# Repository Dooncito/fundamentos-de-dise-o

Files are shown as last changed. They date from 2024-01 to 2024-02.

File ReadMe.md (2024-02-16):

# <p align="center"> Análisis sobre la contaminación atmósfera por las causas de combustibles contaminantes📊 </p>

Proyecto de monitoreo del CO,CO2 y particulas PM2.5 emitidas por el uso de comsbustibles fósiles. 
Datos de experimentales:

- Co (monoxido de carbono):
- CO2 (dioxido de carbono):

- Pm2.5 (materia particulado 2.5):

Plataforma para ver los datos:
https://stem.ubidots.com/app/dashboards/

usuario: doncito;
contraseña: Rodigro17daniel

Si desea conoce más de nosotros [dale click AQUI.](https://github.com/Dooncito/fundamentos-de-dise-o/blob/main/FdD/Entregables/Sobre_nosotros.md)

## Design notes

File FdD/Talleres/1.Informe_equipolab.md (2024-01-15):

## INTRODUCCIÓN A LOS EQUIPOS E INSTRUMENTOS DEL LABORATORIO 
Se muestra lo desarrollado en el laboratorio para conocer y manipular los equipos e instrumentos electrónicos básicos, además reconoce y verifica las características de medición eléctrica con el multímetro.

### Indice:

* [Materiales](#materiales)
* [Uso del multímetro y Fuente de alimentación](#uso-del-multímetro-y-fuente-de-alimentación)
   * [Promedio de errores absoluto y relativo](#promedio-de-errores-absoluto-y-relativo)
   * [Fotos de los Datos](#fotos-de-todos-los-datos)
* [Uso del Generador de Señales y Osciloscopio](#uso-del-generador-de-señales-y-osciloscopio) 
  * [Valores ajustados de la grafica](#valores-ajustados-de-la-grafica) 
  * [Valores medidos de la señal de entrada en un periodo](#valores-medidos-de-la-señal-de-entrada-en-un-periodo)

Documento: https://docs.google.com/document/d/15lO--RKTINXHAl-uv1xj17NnePU8hNBNqTpfqMAFmqM/edit?usp=sharing

## Materiales
   * Fuente de alimentación regulable (HY3005BC )
   * Multímetro Digital (UT139C)
   * Generador de Señales (AFG1022)
   * Osciloscopio Digital (TBS 1000C Series)
   * Cable BNC Male-Male 
   * Par de cables cocodrilos
   * Punta de osciloscopio con conector BNC (Male)

## Uso del multímetro y Fuente de alimentación

### Promedio de errores absoluto y relativo:
<div style="text-align:center;">
	<table border="1" style="margin: 0 auto;">
		<tr>
            <td>N°</td>
			<td>Valor Real</td>
			<td>Valor medio</td>
            <td>Error Absoluto</td>
            <td>Error relativo</td>
		</tr>
		<tr>
			<td>1</td>
			<td>5.00 V</td>
            <td>5.00 V</td>
            <td>0.00 V</td>
            <td>0%</td>
		</tr>
		<tr>
			<td>2</td>
			<td>6.00 V</td>
            <td>5.99 V</td>
            <td>0.01 V</td>
            <td>0.16% - 0.0016</td>
		</tr>
		<tr>
			<td>3</td>
			<td>7.00 V</td>
            <td>6.98 V<d>
            <td>0.02 V</td>
            <td>0.286% - 0.00286</td>
		</tr>
        <tr>
			<td>4</td>
			<td>8.00 V</td>
            <td>7.98 V</td>
            <td>0.01 V</td>
            <td>0.125% - 0.00125</td>
		</tr>
        <tr>
			<td>5</td>
			<td>9.00 V</td>
            <td>8.98 V</td>
            <td>0.02 V</td>
            <td>0.2% - 0.002</td>
		</tr>
        <tr>
			<td>6</td>
			<td>10.00 V</td>
            <td>9.98 V</td>
            <td>0.02 V</td>
            <td>0.2% - 0.002</td>
		</tr>
        <tr>
			<td>7</td>
			<td>11.00 V</td>
            <td>10.98 V</td>
            <td>0.02 V</td>
            <td>0.18% - 0.0018</td>
		</tr>
        <tr>
			<td>8</td>
			<td>12.00 V</td>
            <td>11.98 V</td>
            <td>0.02 V</td>
            <td>0.16% - 0.0016 </td>
		</tr>
        <tr>
			<td>9</td>
			<td>13.00 V</td>
            <td>12.98 V</td>
            <td>0.02 V</td>
            <td>0.154% - 0.00154</td>
		</tr>
        <tr>
			<td>10</td>
			<td>14.00 V</td>
            <td>13.97 V</td>
            <td>0.03 V</td>
            <td>0.214% - 0.002143</td>
		</tr>
        <tr>
			<td colspan="3">Promedio</td>
			<td> 0.017 V</td>
            <td>0.1679% </td>
		</tr>      
	</table>
    </div>
		    
### Fotos de todos los datos

| <!-- --> | <!-- --> | 
|:---:|:---:|
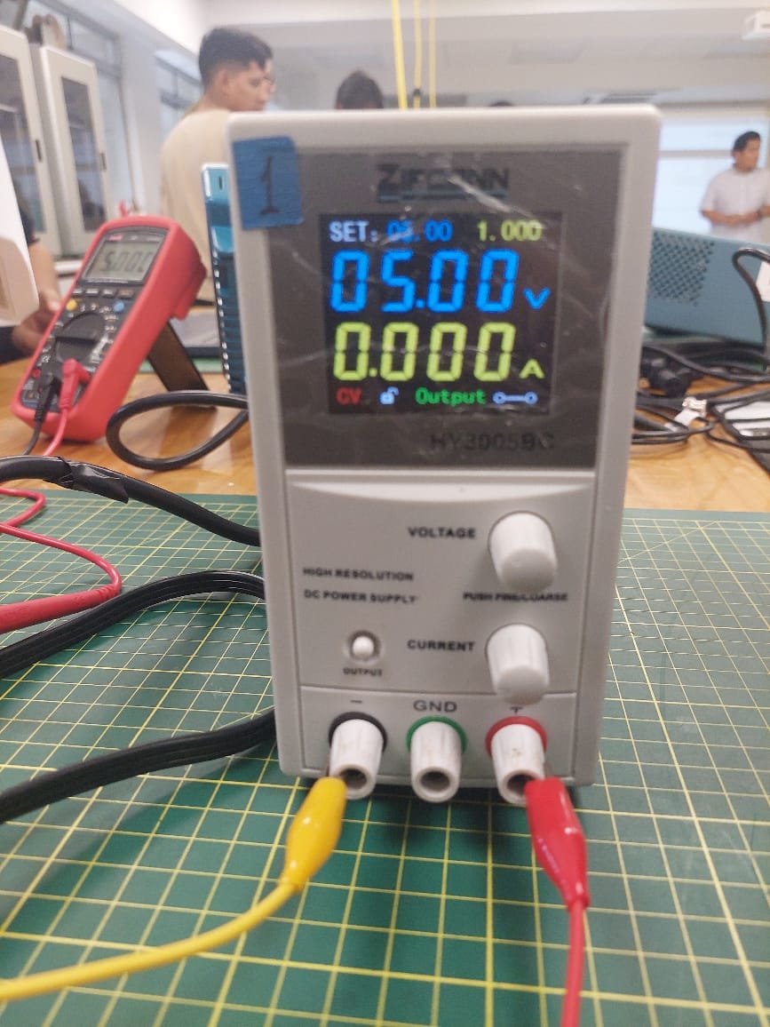
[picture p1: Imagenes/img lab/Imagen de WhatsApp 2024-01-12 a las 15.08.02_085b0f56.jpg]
Dato1
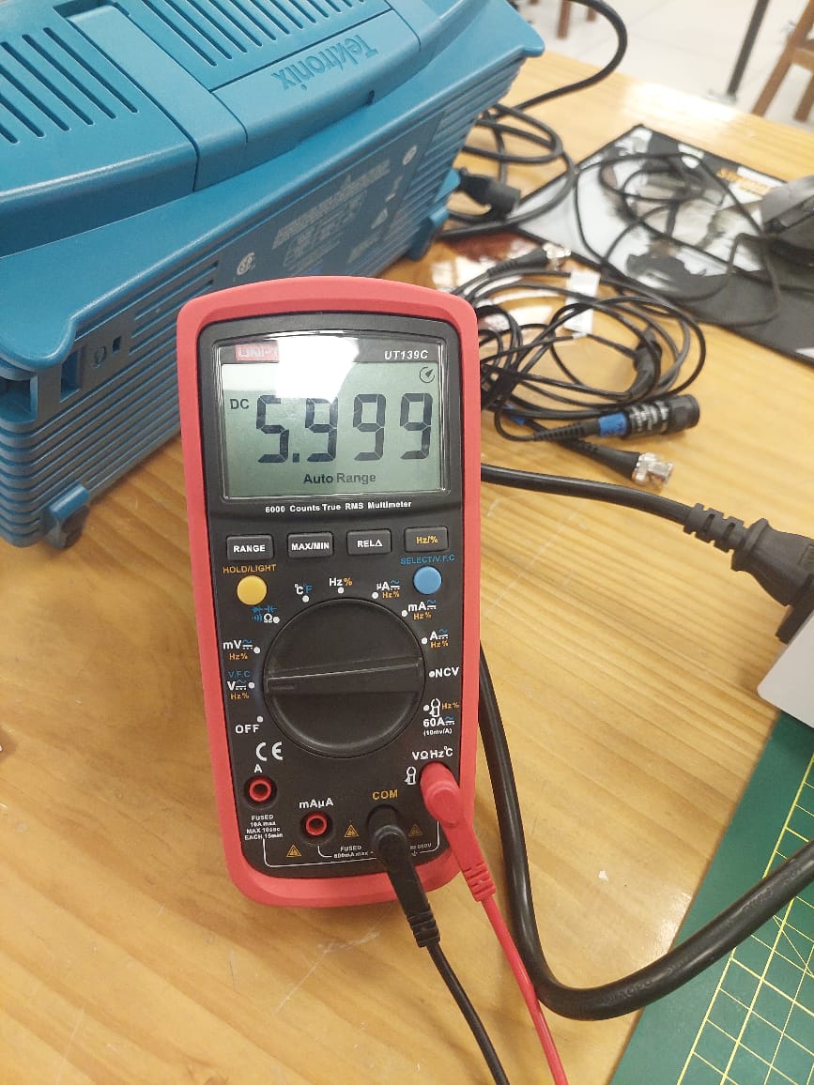
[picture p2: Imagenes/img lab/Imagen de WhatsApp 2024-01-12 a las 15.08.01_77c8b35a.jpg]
dato2
| |   |
| Dato#1 5V | Dato#2 6V | 
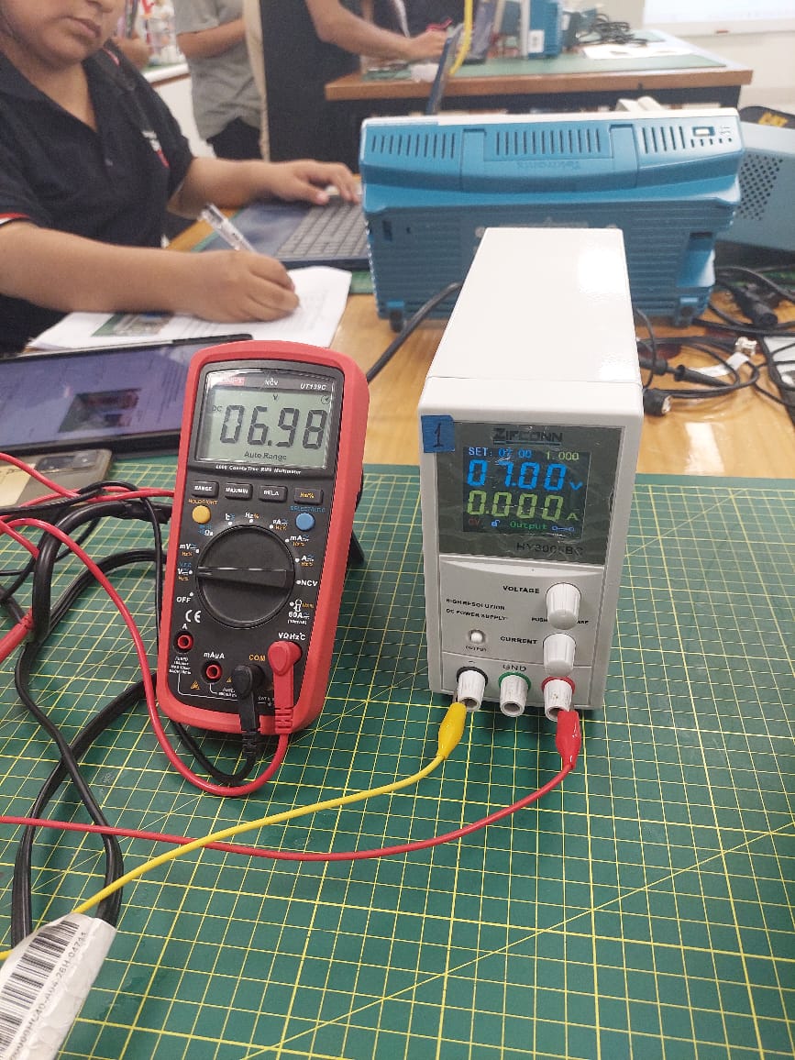
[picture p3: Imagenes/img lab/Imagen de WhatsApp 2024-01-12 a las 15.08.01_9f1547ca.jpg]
Dato3
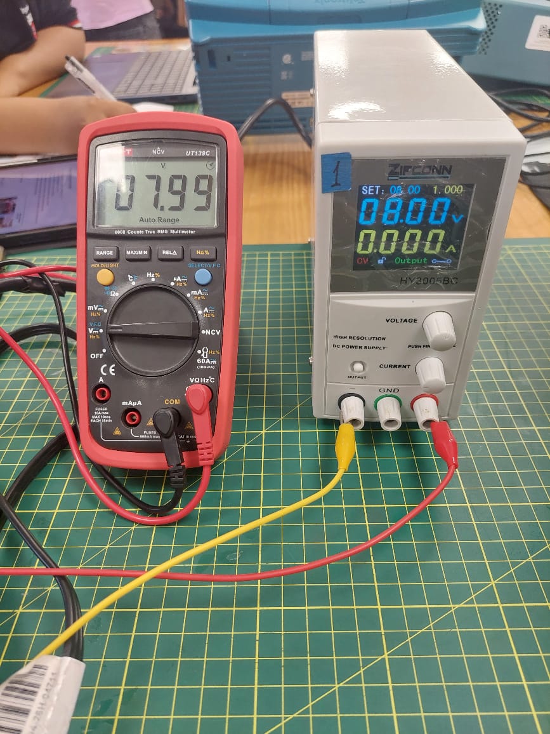
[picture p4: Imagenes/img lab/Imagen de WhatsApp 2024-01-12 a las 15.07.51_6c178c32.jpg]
dato4
| |   |
| Dato#3 7V | Dato#4 8V | 
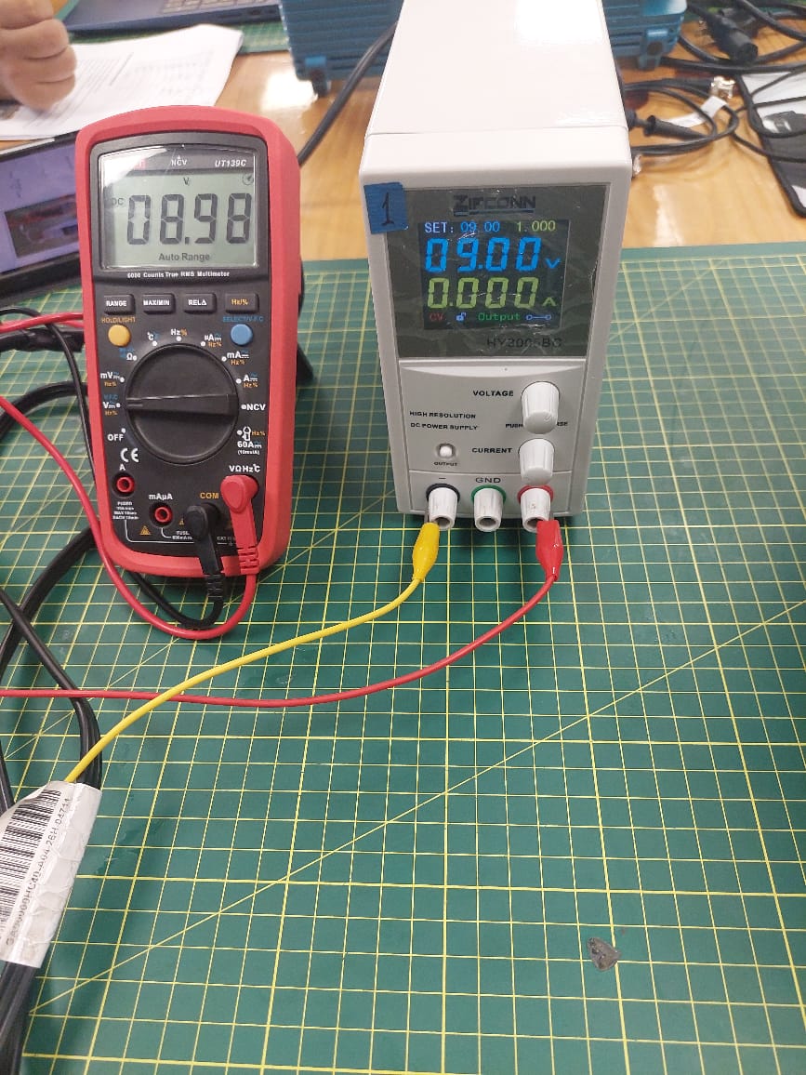
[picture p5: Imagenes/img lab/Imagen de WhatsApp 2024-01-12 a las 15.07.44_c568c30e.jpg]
Dato5
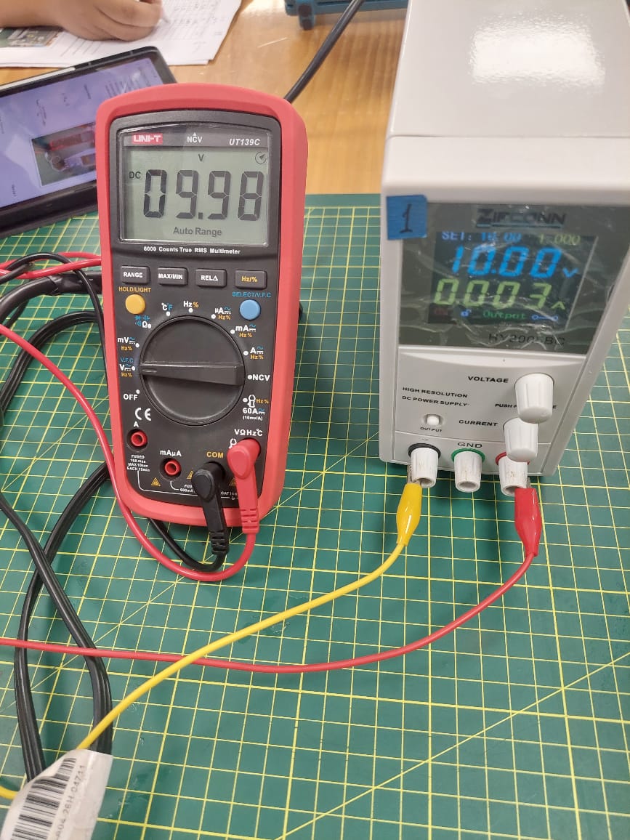
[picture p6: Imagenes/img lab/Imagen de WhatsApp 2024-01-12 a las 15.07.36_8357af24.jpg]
dato6
| |   |
| Dato#5 9V | Dato#6 10V | 
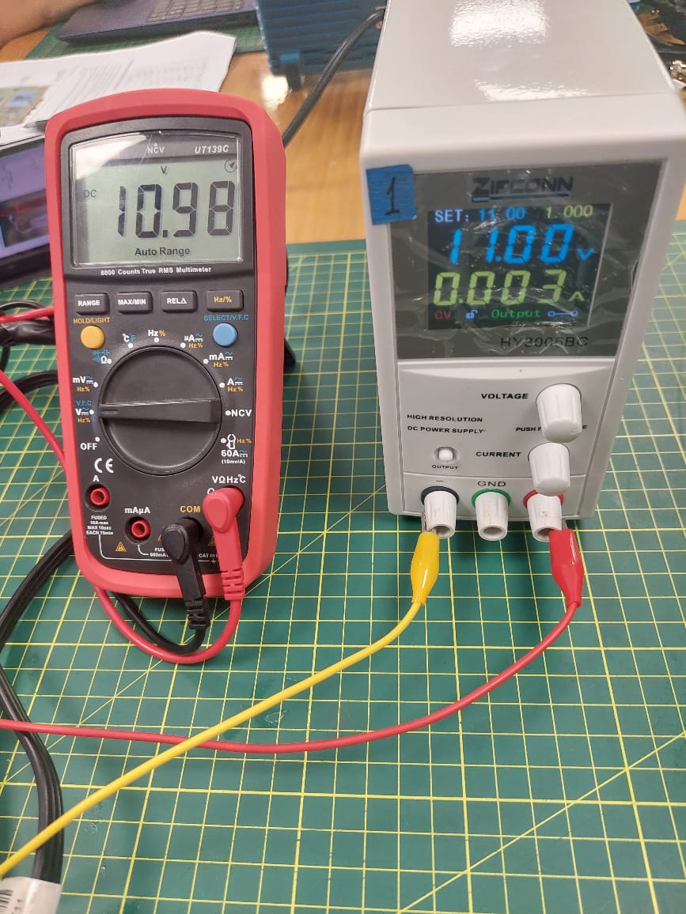
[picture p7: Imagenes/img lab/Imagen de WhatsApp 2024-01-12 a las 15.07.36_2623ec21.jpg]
Dato7
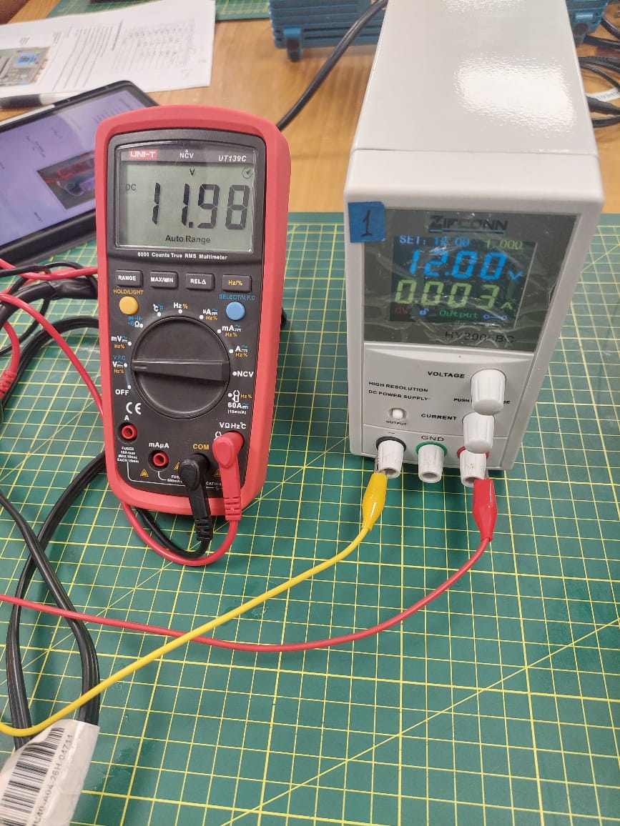
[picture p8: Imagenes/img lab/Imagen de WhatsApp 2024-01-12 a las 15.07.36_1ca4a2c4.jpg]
dato8
| |   |
| Dato#7 11V | Dato#8 12V | 
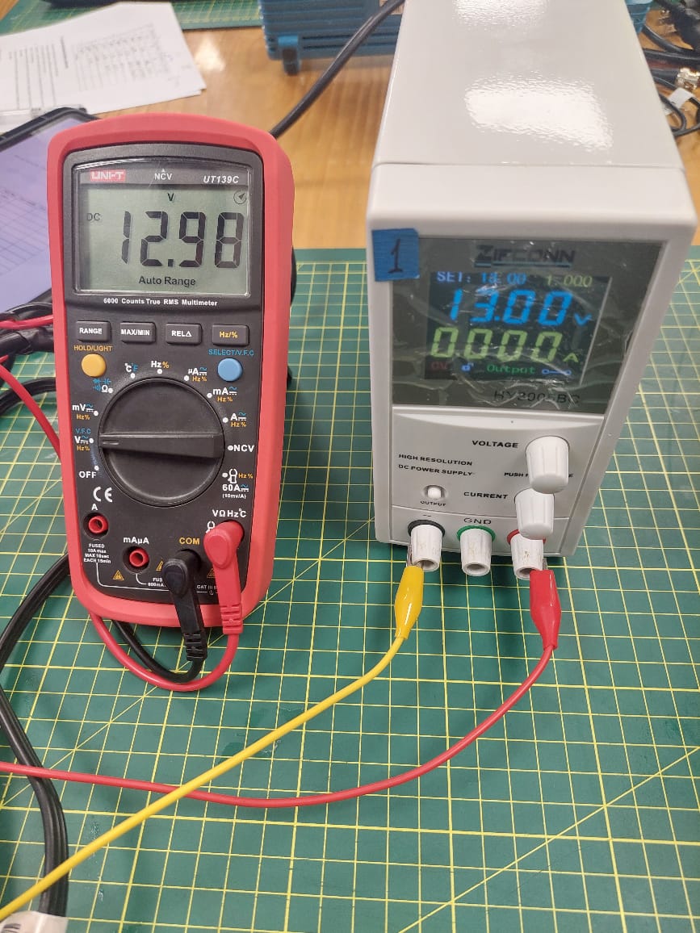
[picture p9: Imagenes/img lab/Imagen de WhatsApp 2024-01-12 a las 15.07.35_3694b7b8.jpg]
Dato9
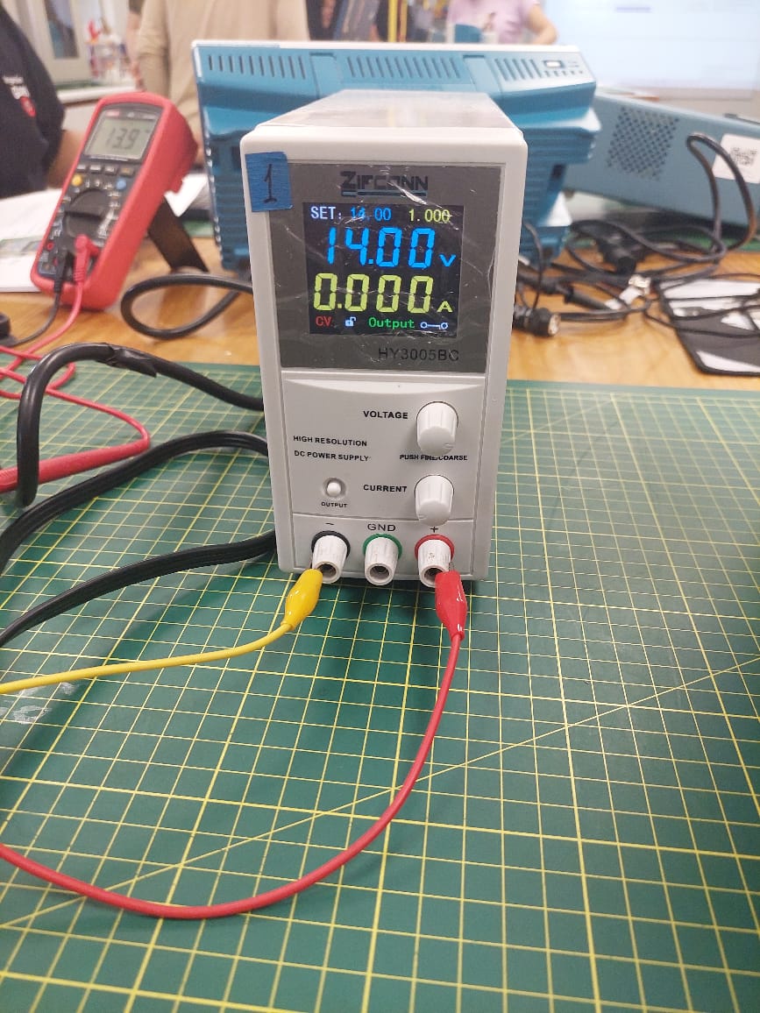
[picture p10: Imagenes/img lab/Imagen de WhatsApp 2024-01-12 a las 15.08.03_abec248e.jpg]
dato10
| |   |
| Dato#9 13V | Dato#10 14V | 

## Uso del Generador de Señales y Osciloscopio

En este experimento la consigna era modificar los parámetros de posición horizontal, vertical y disparo para ajustar la visualización de la señal sinusoidal en el osciloscopio, la cual es obtenida mediante el generador de señales.

Función de los instrumentos usados en esta sesión:

- Generador de señales: Emite señales eléctricas de frecuencias y amplitudes específicas, esencial para probar, calibrar y experimentar con dispositivos electrónicos.

- Osciloscopio digital: Muestra visualmente la forma de onda de señales, permitiendo a los técnicos analizar la amplitud, frecuencia y otros parámetros, con capacidades avanzadas de procesamiento y almacenamiento de datos

Primero conectamos mediante un cable BNC a ambos dispositivos en el canal 1, posteriormente ajustamos el generador de señales en los siguientes parámetros:

 - Frecuencia: 10khz
 - Amplitud: 2,5V
 - Offset: 0V

Descripción de la imagen

### Valores ajustados de la grafica

Se ajustaron los siguientes valores para sincronizar el voltaje en el osciloscopio:
- Escala de división vertical: 665V
- Amplitud máxima: 2.5kV
- Amplitud mínima: 0V
- Tiempo: 20μs
- Tasa de muestreo: 62,5MS/s
- Tiempo de registro: 20k ptos

Valores encontrados post-ajustes:
- Frecuencia: 10kHZ
- Voltaje pico: 1,01kV
- Variación de amplitud: 2,5kV

Al final nó se lograron obtener los valores solicitados, debido a que el valor de la escala de división vertical fue ajustado erroneamente en 665V.

### Valores medidos de la señal de entrada en un periodo 
Valores:
Amplitud: 2.50kV , Periodo: 100 ,Frecuencia : 1/ 100 = 0.01

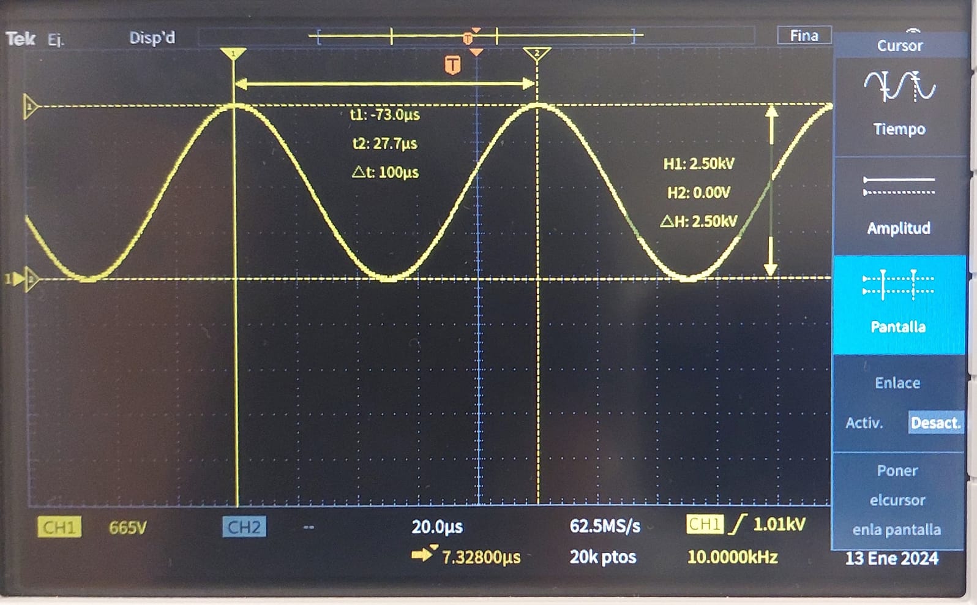
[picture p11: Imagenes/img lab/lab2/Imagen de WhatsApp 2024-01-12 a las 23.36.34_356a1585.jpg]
Descripción de la imagen


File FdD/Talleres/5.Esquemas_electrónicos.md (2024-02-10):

# <h1 align= "center"> **Esquemático del circuito electrónico**</h1>

### Integrantes:
* Said Andre Quispe Diaz
* Hermoza Quispe, Daniel Rodrigo
* Acevedo Valer, Milagros Soledad
* Jander Huamani Salazar
### Lista de contenido:
* [Introducción](#introducción) 
* [Objetivo](#objetivo)
* [Plataforma](#¿cuáles-son-las-ventajas-de-utilizar-la-plataforma-fluxia)
* [Componentes](#componentes-a-utilizar)
* [Desarrollo](#explicación-del-esquema)
* [Esquema](#esquema-del-ejercicio)

### Introducción: 
  El esquemático del circuito electrónico es esencial en todas las etapas del ciclo de vida de un proyecto electrónico, desde el diseño inicial hasta la implementación y el mantenimiento. Proporciona una representación visual clara y concisa que facilita el diseño, análisis, documentación y comunicación de los circuitos electrónicos.
### Objetivo: 
En el presente taller se utilizará la IA Flux como plataforma para la creación del esquemático de circuito eléctrico, en la cual usaremos como mínimo 6 componentes para dicha creación, mencionando el uso que tendrá cada componentes dentro del esquema de circuito eléctrico .
### ¿Cuáles son las ventajas de utilizar la plataforma Flux.ia?
La ventaja que tiene dicha IA con respecto a la competencia es su capacidad para mejorar la eficiencia de creación, automatizar tareas respectivas, optimización del diseño del esquema, detección de errores y proporcionar una experiencia de usuario fácil y accesible. Lo que conduce a un proceso de diseño más rápido, preciso y efectivo en general. 

## Ejercicio con más de 6 componentes
### Componentes a utilizar:
1. **LEDs (Diodo Emisor de Luz):**  
    * **Descripción:** Los LEDs son dispositivos semiconductores que emiten luz cuando una corriente eléctrica pasa a través de ellos en una dirección específica. Son ampliamente utilizados en circuitos electrónicos para indicación visual.

    * **Función en el circuito:** Proporcionan retroalimentación visual al usuario o cumplen una función específica, como indicar el estado de un sistema.

2. **Sensor LDR (Resistor Dependiente de la Luz):** 
    * **Descripción:** Un sensor LDR es un tipo de resistor cuya resistencia varía en función de la intensidad de la luz incidente sobre él. Su resistencia disminuye a medida que aumenta la luz.
    * **Función en el circuito:** Detecta niveles de luz ambiental y puede ser utilizado para activar o desactivar componentes electrónicos en respuesta a cambios en la iluminación.

3. **Buzzer(Zumbador):** 
    * **Descripción:** Un buzzer es un transductor electromecánico que convierte señales eléctricas en sonido. Consiste en un diafragma vibratorio que produce sonido cuando se le aplica corriente eléctrica.
    * **Función en el circuito:** Emite señales audibles para alertar al usuario o indicar ciertas condiciones en el circuito, como alarmas o notificaciones

4. **Botón Pulsador:**
    * **Descripción:** Un botón pulsador es un interruptor momentáneo que se activa al ser presionado y se desactiva cuando se suelta. Cuando está presionado, conecta temporalmente dos terminales eléctricos.
    * **Función en el circuito:** Proporciona una entrada controlada por el usuario para iniciar o detener funciones específicas del circuito, como iniciar un proceso o cambiar un estado.
5. **Resistencia de 10k ohmios:**
    * **Descripción:** Una resistencia de 10k ohmios es un componente electrónico que limita el flujo de corriente en un circuito. Su valor de resistencia es de 10,000 ohmios.
    * **Función en el circuito:** Se utiliza para limitar la corriente en el sensor LDR o en circuitos de pull-up/pull-down para botones pulsadores.
6. **Resistencia de 220 ohmios:**
    * **Descripción:** Una resistencia de 220 ohmios es un componente electrónico que limita el flujo de corriente en un circuito. Su valor de resistencia es de 220 ohmios.
    * **Función en el circuito:** Se utiliza para limitar la corriente en los LEDs, protegiéndolos de daños debido a corrientes excesivas.
7. **Arduino Nano:**
    * **Descripción:** El Arduino Nano es una placa de desarrollo basada en microcontroladores ATmega de Atmel. Tiene un tamaño compacto y proporciona un entorno de desarrollo fácil de usar para proyectos electrónicos.
    * **Función en el circuito:** Controla y coordina las operaciones de los diferentes componentes del circuito mediante el programa cargado en su memoria.
8. **Pantalla:**
    * **Descripción:** Una pantalla es un dispositivo de salida que muestra información visual, como texto, gráficos o números. Puede haber diferentes tipos de pantallas, como LCD (pantallas de cristal líquido), OLED (diodo orgánico emisor de luz) o LED (diodo emisor de luz).
    * **Función en el circuito:** Proporciona retroalimentación visual al usuario mostrando datos relevantes, como valores de sensores, mensajes de estado o resultados de cálculos.
9. **Potenciómetro:**
    * **Descripción:** Un potenciómetro es un dispositivo resistivo con un contacto deslizante que se mueve a lo largo de una pista resistiva. Al ajustar su posición, se puede variar la resistencia eléctrica entre sus terminales.
    * **Función en el circuito:** Permite al usuario ajustar manualmente el valor de resistencia en el circuito, lo que puede controlar características como el brillo de una pantalla, el volumen de un altavoz o la velocidad de un motor.

## **Explicación del esquema**
Se trata de un sistema de alarma que opera mediante la detección de la luminosidad ambiental. Para llevar a cabo esta función, se emplea un sensor LDR (Light Dependent Resistor), el cual activa los zumbadores (buzzers) y los diodos emisores de luz (LEDs) en caso de detectar luz. Además, se utiliza una pantalla LCD para mostrar un mensaje que incluye la hora actual y un texto personalizado.

Para desactivar la alarma y detener el sonido de los zumbadores, se ha incorporado un botón pulsador (push button), el cual al ser accionado apaga tanto los LEDs como los buzzers.

En el diseño del circuito se han incluido resistencias de 10kΩ, 100Ω y 220Ω para garantizar una correcta conversión de energía, evitando así posibles daños a los componentes electrónicos y asegurando un adecuado rendimiento en términos de sonido y luminosidad. También se usó un potenciómetro para ajustar el brillo de la pantalla LCD.

## Esquema del ejercicio
<p align= "center">
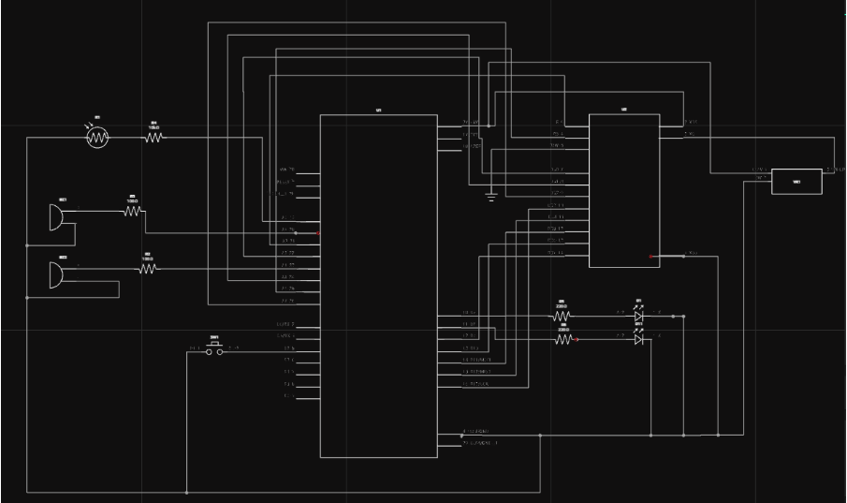
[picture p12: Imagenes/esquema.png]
</p><p align= "center">Imagen 1. Esquemático </p>

[Visualización en Flux.ai](https://www.flux.ai/doncito/advanced-lime-warp-drive?editor=schematic)

## **Conclusión**
En conclusión, hemos desarrollado un sistema de alarma que utiliza un sensor LDR para detectar la luz ambiental y activar los buzzers, LEDs y pantalla LCD. La inclusión de un botón pulsador permite desactivar la alarma fácilmente, también un potenciometro para ajustar el brillo de la pantalla LCD. Además, hemos cuidado la elección de resistencias para asegurar un funcionamiento eficiente y proteger los componentes electrónicos. Este sistema puede servir para la detección de luz en entornos específicos o como una alarma alternativa.

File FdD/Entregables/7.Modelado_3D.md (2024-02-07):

# <h1 align="center">🖋Modelado 3D del Prototipo 🔩</h1>
### Lista de contenido:
* [Tabla de componentes](#tabla-de-componentes)
* [Modelo del prototipo](#modelo-del-prototipo) 
* [Interior del prototipo](#interior-del-prototipado)
* [Ubicación](#ubicación-del-prototipo) 
* [Modelos de los componentes](#componentes) 

## Tabla de componentes
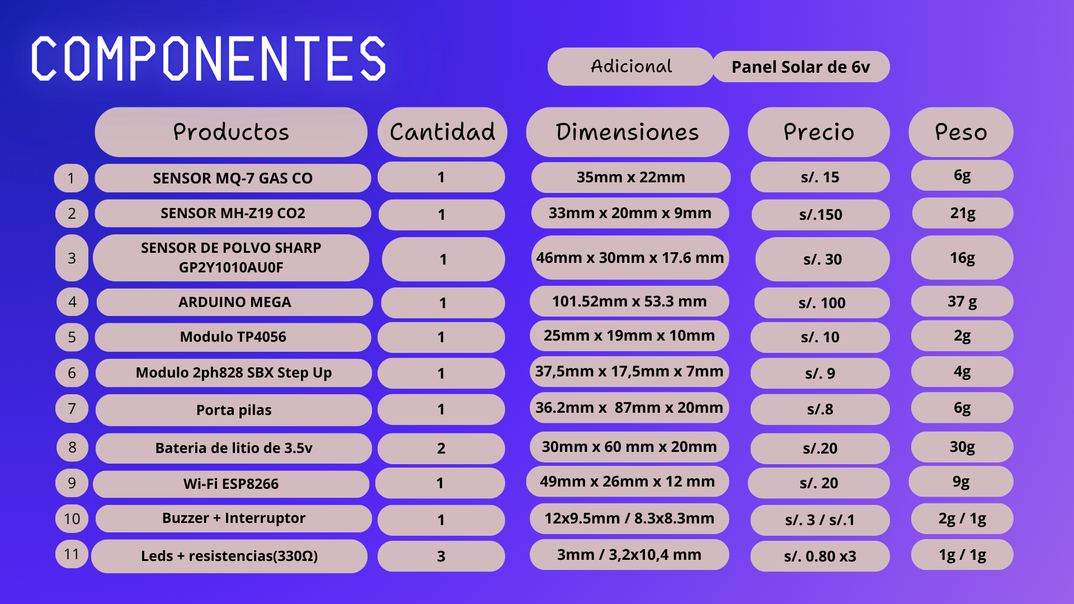
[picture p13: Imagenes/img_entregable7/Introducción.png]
imagen


## Modelo del prototipo
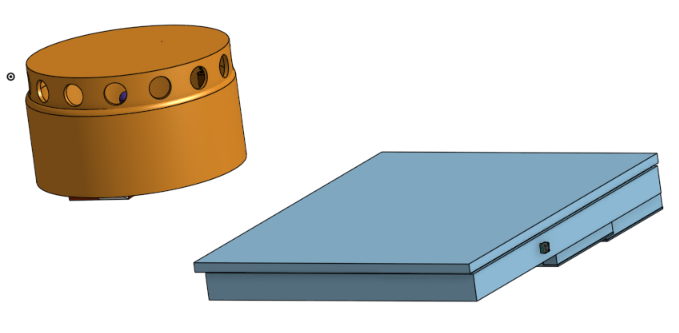
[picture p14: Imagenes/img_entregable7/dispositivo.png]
<p  align="center"> **Figura1. Dispositivos** </p>

[**Modelo en onshape**](https://cad.onshape.com/documents/174262e779d590e9f69711e3/w/334a1c3685cb40d3d7fd8273/e/c486e682bcecdcdf7f70a628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)

## Interior del prototipado
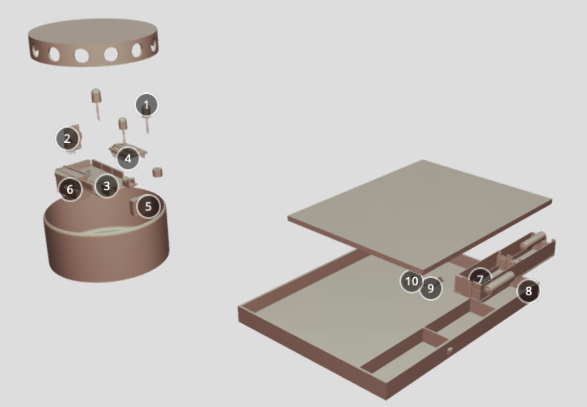
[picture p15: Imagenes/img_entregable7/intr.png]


<p style="font-size: 13px; font-weight: normal; margin: 5px; color: #4A4A4A;"> <a href="https://sketchfab.com/3d-models/componente-delprototipo-426003c9df2746469747df32c877d202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" target="_blank" rel="nofollow" style="font-weight: bold; color: #1CAAD9;"> componente_delprototipo </a> by <a href="https://sketchfab.com/sol29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" target="_blank" rel="nofollow" style="font-weight: bold; color: #1CAAD9;"> sol29 </a> on <a href="https://sketchfab.com?utm_medium=embed&utm_campaign=share-popup&utm_content=426003c9df2746469747df32c877d202" target="_blank" rel="nofollow" style="font-weight: bold; color: #1CAAD9;">Sketchfab</a></p>

|N°|Producto|Cantidad|
|:--:|:----:|:----:|
|1|Leds|3|-
|2|Mq-7 Co|1|-
|3|Arduino Mega|1|-
|4|Esp8266|1|-
|5|Módulo MH-Z19B|1|-
|6|GP2Y1010AU0F|1|-
|7|Porta pila|1|
|8|Pila de litio|2|-
|9|2ph828 SBX Step Up|1|
|10|Modulo TP4056|1|-

#### Modelado3D
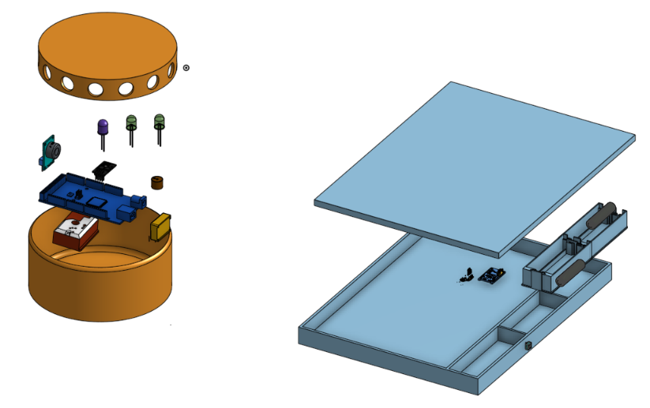
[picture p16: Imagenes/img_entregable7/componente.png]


[**Modelo en onshape**](https://cad.onshape.com/documents/174262e779d590e9f69711e3/w/334a1c3685cb40d3d7fd8273/e/2e112188205770a7f79addcc)

## Ubicación del prototipo
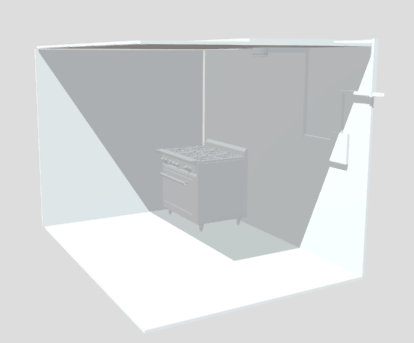
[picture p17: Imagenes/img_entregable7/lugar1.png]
imagen
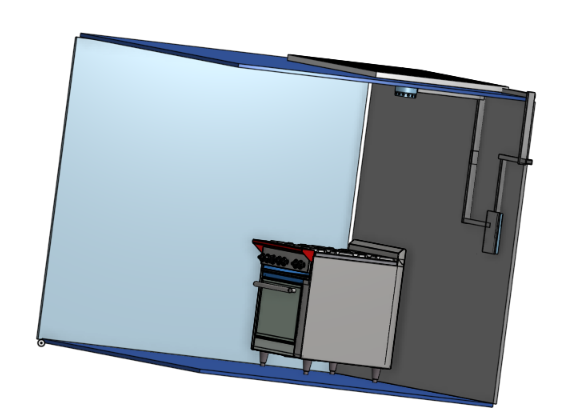
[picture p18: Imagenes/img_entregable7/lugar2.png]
imagen
|<p>Animación interactivad</p> <p style="font-size: 13px; font-weight: normal; margin: 5px; color: #4A4A4A;"> <a href="https://sketchfab.com/3d-models/prototipo-instalado-753c06a51ffa4db28d9ecfe310c25142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" target="_blank" rel="nofollow" style="font-weight: bold; color: #1CAAD9;"> Prototipo instalado </a> by <a href="https://sketchfab.com/doncito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" target="_blank" rel="nofollow" style="font-weight: bold; color: #1CAAD9;"> doncito </a> on <a href="https://sketchfab.com?utm_medium=embed&utm_campaign=share-popup&utm_content=753c06a51ffa4db28d9ecfe310c25142" target="_blank" rel="nofollow" style="font-weight: bold; color: #1CAAD9;">Sketchfab</a></p></div>|<p>Ubicación del prototipo [**Modelo en onshape**](https://cad.onshape.com/documents/174262e779d590e9f69711e3/w/334a1c3685cb40d3d7fd8273/e/2e112188205770a7f79addcc)</p> |
|:---:|:--:|

## Componentes

|Modelo del Componente|Enlaces |
|:---|:---|
|Arduino Mega.| Recuperado de https://grabcad.com/library/arduino-mega-11|
|Esp8266.|Recuperado de https://grabcad.com/library/esp-01s-1| 
|Leds. |Recuperado de https://grabcad.com/library/led-3mm-verde-by-oscarml-1|
|MH-Z19.| Recuperado de https://grabcad.com/library/mh-z19b-c02-module-detector-mh-z19-1|
|Módulo 2ph828 SBX Step Up.| Recuperado de https://grabcad.com/library/st6845-c-1|
|MQ-7.| Recuperado de https://grabcad.com/library/mq135-air-sensor-1|
|Pilas. |Recuperado de https://grabcad.com/library/bateria-18650-panasonic-1|
|Sensor de partículas.| Recuperado de https://grabcad.com/library/dust-sensor-gp2y1010au0f-1|
|TP4056.| Recuperado de https://grabcad.com/library/modulo-carga-tipo-c-bateria-de-litio-tp4056-18650-1|

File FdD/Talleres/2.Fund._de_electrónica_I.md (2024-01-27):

# INTRODUCCIÓN A LOS CIRCUITOS ELECTRÓNICOS I
### Indice:
* [Materiales](#materiales)
* [Manejo del protoboar](#manejo-del-protoboar)
   * [Ejercicio 1🐣](#ejercicio-1)
   * [Ejercicio 2🐈](#ejercicio-2)
   * [Ejercicio 3🐲](#ejercicio-3)
* [Circuitos divisor de tensión](#circuitos-divisores-de-tensión)
## Materiales
   * Kit B de electrónica 
   * Multímetro (UT139C)
   * Fuente de laboratorio 
 
## Manejo del protoboar
### Ejercicio 1
Para este ejercicio usamos resistencia de 1KΩ, 100KΩ y 220Ω; donde identificamos que estan en series y paralelo el circuito.
#### Clasificacion de resistencia:
* R1 = 1KΩ 
* R2 = 100KΩ
* R3 = 220Ω
<table style="width: 100%;">
    <tr>
       <td style="border: 0px solid #ddd; padding: 4px; text-align: center;">
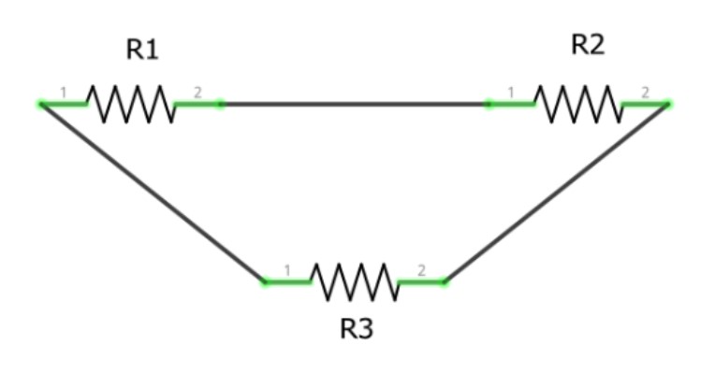
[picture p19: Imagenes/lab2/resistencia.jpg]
            
       </td>        
       <td>
       <h3>Resolución:</h3>
       <p>Primero la parte de serie.</p>
       <p>1KΩ + 100KΩ = 101KΩ</p>
       <p>Después lo de paralelo.</p>
       <p> 1/Req = 1 / 101KΩ + 1/220Ω </p>
       <p> Req = 219.52Ω</p>
       </td>
    </tr>
</table>
Procedimiento en el laboratorio: 

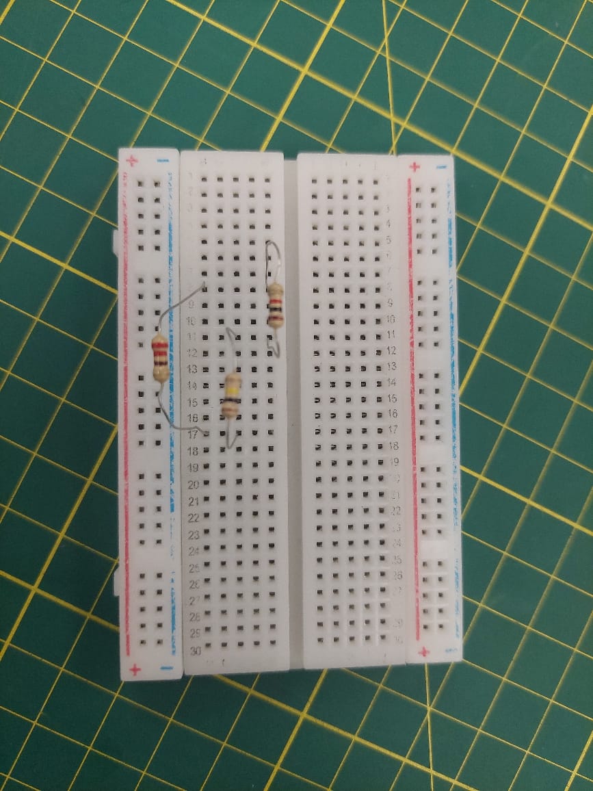
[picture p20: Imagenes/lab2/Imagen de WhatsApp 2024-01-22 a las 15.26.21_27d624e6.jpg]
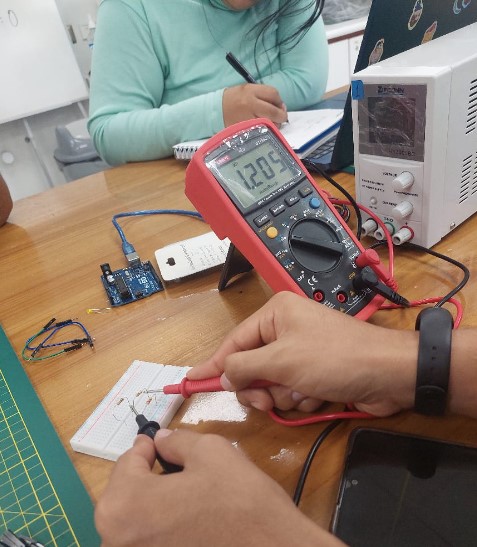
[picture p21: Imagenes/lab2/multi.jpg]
|  |    |
|:--:|:--:|

### Ejercicio 2
Para este ejercicio usamos resistencia de 1KΩ, 10KΩ, 100KΩ y 220Ω; donde identificamos que estan en series y paralelo el circuito.
#### Clasificacion de resistencia:
* R1 = 1KΩ 
* R2 = 100KΩ
* R3 = 220Ω
* R4 = 1KΩ
* R5 = 10KΩ
<table style="width: 100%;">
    <tr>
       <td style="border: 0px solid #ddd; padding: 4px; text-align: center;">
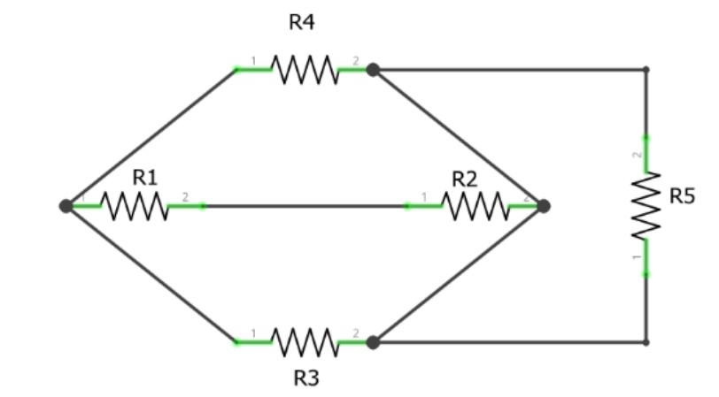
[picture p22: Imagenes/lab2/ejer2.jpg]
            
       </td>        
       <td>
       <h3>Resolución:</h3>
       <p>Primero la parte de serie.</p>
       <p>1KΩ + 100KΩ = 101KΩ</p>
       <p>Después lo de paralelo.</p>
       <p> 1/Req = 1 / 101KΩ + 1/220Ω + 1/1KΩ</p>
       <p> Req = 180Ω</p>
       </td>
    </tr>
</table>
Procedimiento en el laboratorio: 

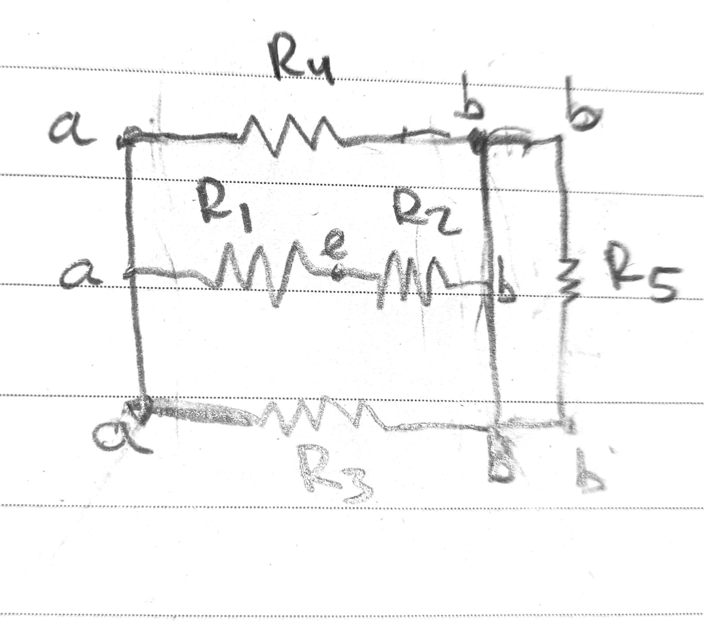
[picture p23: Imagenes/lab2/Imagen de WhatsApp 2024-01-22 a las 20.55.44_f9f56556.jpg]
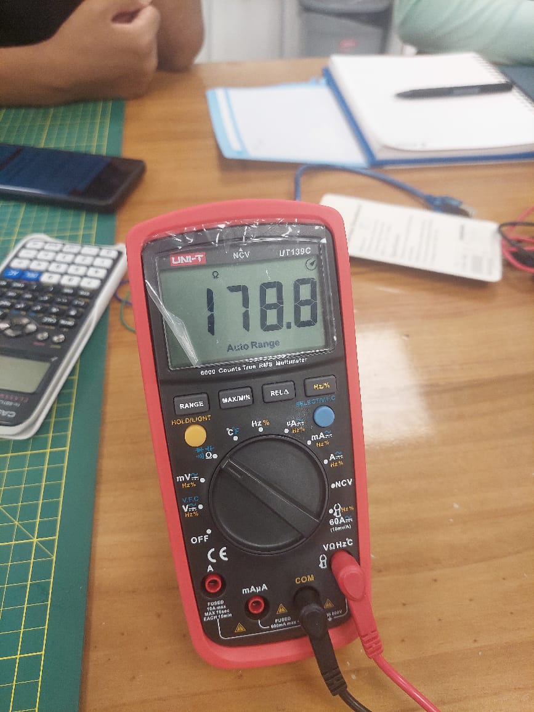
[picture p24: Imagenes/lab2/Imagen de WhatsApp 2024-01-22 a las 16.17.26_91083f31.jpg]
|  |    |
|:--:|:--:|

### Ejercicio 3
Para este ejercicio usamos resistencia de 1KΩ, 10KΩ, 100KΩ y 220Ω; donde identificamos que estan en series y paralelo el circuito.
#### Clasificacion de resistencia:
* R1 = 220Ω 
* R2 = 100KΩ
* R3 = 220Ω
* R4 = 1KΩ
* R5 = 1KΩ
* R6 = 10KΩ
<table style="width: 100%;">
    <tr>
       <td style="border: 0px solid #ddd; padding: 4px; text-align: center;">
            
       </td>        
       <td>
       <h3>Resolución:</h3>
       <p>Primero las partes de serie.</p>
       <p>200Ω + 200Ω = 440Ω</p>
       <p>10KΩ + 1KΩ = 11KΩ</p>
       <p>1KΩ + 100KΩ = 101KΩ</p>
       <p>Después lo de paralelo.</p>
       <p> 1/Req = 1 / 440Ω + 1/11KΩ + 1/101KΩ</p>
       <p> Req = 420Ω</p>
       </td>
    </tr>
</table>
Procedimiento en el laboratorio: 

|  |    |
|:--:|:--:|

## Circuitos divisores de tensión
Para este ejercicio nos pide cuales seria las resistencia para que nos salga un voltaje de 1.1v.
#### Clasificación de voltaje:
* Vin = 5v
* Vout = 1.1v
<table style="width: 100%;">
    <tr>
       <td style="border: 0px solid #ddd; padding: 4px; text-align: center;">
            
       </td>        
       <td>
       <h3>Resolución:</h3>
       <p>1.1v = R2 X (5v/(R1+R2))</p>
       <p>1.1(R1+R2) = 5R2 </p>
       <p>1.1R1 = 5R2- 1.1R2</p>
       <p>R1 = 3.54R2 </p>
       <p>Siendo que: </p>
       <p>R2 = 1KΩ y R1 = 3.5KΩ</p>
       <p>Así que: </p> 
       <p>R2 tiene un voltaje 1.1V</p>
       </td>
    </tr>
</table>
Procedimiento en el laboratorio: 

Para llegar a esa lógica de que la R1 usara 6 resistencia, el cual al aplicar la fórmula se llego a que R1 es igual a 3.54 veces R2, entonces nos dimos cuenta de que el valor de R2 tenia que ser 1k ohmios. Posteriormente se necesita igualar el dato 3,5 entonces planteamos 3 resistencias en serie de 1K ohmios y para que nos de 0,5K ohmios propusimos 2 resistencias en paralelo de 1K ohmios cada una. Por consiguiente nos daria la suma de esas 5 resistencias 3,5.

Para finalizar utilizamos 1 resistencia R2 siguiendo con el diseño del ejercicio y se finalizó al obtener en la salida 1,1V.

|  |    |
|:--:|:--:|

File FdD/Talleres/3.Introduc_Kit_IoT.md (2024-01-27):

# <p align="center"> Uso del los implementos de IoT</p>
### Descripción de IoT
Concepto que describe la interconexión de dispositivos físicos a través de la red, permitiéndoles recopilar y compartir datos entre sí.
### Integrantes : 
* Acevedo Valer, Milagros Soledad 
* Quispe Diaz, Said Andre
* Hermoza Quispe, Daniel Rodrigo 

## Indice 
* [Introducción del laboratori](#introducción)
* [Materiales](#materiales)
* [Procedimiento y desarrollo](#procedimiento-y-desarrollo)
    * [Temperatura y Humerada](#ejercicio-1)
    * [Temperatura en Celsius-Fahrenheit-Kelvin](#ejercicio-2)
    * [Funcionamiento de led y PIR](#ejercicio-3)
* [Conclusión](#conclusión)
## Introducción 
En esta oportunidad, exploramos las funcionalidades de Arduino, como el Arduino MKR WiFi 1010 y el MKR IoT Carrier. Durante la actividad, se llevaron a cabo prácticas como el registro local de temperatura y humedad, la visualización de la temperatura en Celsius, Fahrenheit y Kelvin. Además, la activación de luces mediante un sensor de movimiento, indicando la temperatura mediante luces de LEDs azules o rojas.
## Materiales 
El Arduino Explore IoT Kit incluye: 

* Arduino MKR WiFi 1010
* Arduino MKR IoT Carrier Board 
* Micro USB cable
* PIR sensor
<p align="center"> 
</p>

## Procedimiento y Desarrollo 
Demostración del proceso de construcción y codificación. 
### Ensamblaje del Equipo  
Comenzamos reconociendo los complementos que nos proporciona el Kit, empezando armarlo y utilizar el Arduino Cloud. 
Tenemos que unir el el Arduino MKR WiFi 1010 y el MKR IoT Carrier, tambien nos inincluye una carcasa de plástico para poner el Carrier. Para poder usarlo en las explicaciones del código, para poder utilizar las funcione con el encapsulado.  


### Ejercicio #1
### **Lectura de temperatura y humedad**
Para comenzar tenemos que tener instalado todo lo que nos pide (https://app.arduino.cc/) para poder codificar y programar la MKR IoT Carrier.
Siguiendo los pasos para comentar toda la parte del codigo, y la unica parte que podriamos cambiar es dependiendo si estamos usando la carcasa o no. 
```cpp
 CARRIER_CASE = false //Si no usamos la carcasa
 CARRIER_CASE = true  //Si lo usamos 
``` 
Además teniendo descargado la libreria **_Arduino_MKRIoTCarrier_** para que el codigo funcione. 
#### Codigo completo: 
```cpp
#include <ArduinoBLE.h>
#include <Arduino_MKRIoTCarrier_Qtouch.h>
#include <Arduino_MKRIoTCarrier_Relay.h>
#include <EnvClass.h>
#include <IMUClass.h>
#include <MKRIoTCarrierDefines.h>
#include <PressureClass.h>
#include <Arduino_MKRIoTCarrier.h>

MKRIoTCarrier carrier;

float temperature = 0;
float humidity = 0;
void setup() {
  Serial.begin(9600);
  CARRIER_CASE = true;
  carrier.begin();
}
void loop() {
  temperature = carrier.Env.readTemperature();
  humidity = carrier.Env.readHumidity();
  carrier.Buttons.update();
 
  Serial.print("Temperature = ");
  Serial.print(temperature);
  Serial.println(" Â°C");
 
  Serial.print("Humidity = ");
  Serial.print(humidity);
  Serial.println(" %");

  if (carrier.Buttons.onTouchDown(TOUCH0)) {
    printTemperature();
  }
 
  if (carrier.Buttons.onTouchDown(TOUCH1)) {
    printHumidity();
  }
}
void printTemperature() {
  carrier.display.fillScreen(ST77XX_RED); //red 
  carrier.display.setTextColor(ST77XX_WHITE); //text
  carrier.display.setTextSize(6); 
 
  carrier.display.setCursor(30, 50); 
  carrier.display.print("Temp: ");
  carrier.display.setTextSize(4); 

  carrier.display.setCursor(40, 120);
  carrier.display.print(temperature);
  carrier.display.print(" C");
}
 
void printHumidity() {
  carrier.display.fillScreen(ST77XX_BLUE); 
  carrier.display.setTextColor(ST77XX_WHITE); 
  carrier.display.setTextSize(2); 
 
  carrier.display.setCursor(20, 110);
  carrier.display.print("Humi: ");
  carrier.display.print(humidity);
  carrier.display.println(" %");
}
``` 

### Ejercicio #2
### **Cambio de temperatura (Celsius(°C)-Fahrenheit(°F) y Kelvin(K))** 
Para este ejercicio, podemos utilizar el mismo código, modificando algunas partes del contenido de la función `void printTemperature()`. Sin embargo, debido a limitaciones de tiempo y errores en el código que no funcionaban correctamente en su momento, no pudimos mostrar el resultado con imágenes.

``` cpp
#include <Arduino_MKRIoTCarrier.h>
MKRIoTCarrier carrier;
double temperature = 0;
float humidity = 0;

void setup() {
  Serial.begin(9600);
  CARRIER_CASE = true;
  carrier.begin();
}

void loop() {
  temperature = carrier.Env.readTemperature();
  humidity = carrier.Env.readHumidity();
  carrier.Buttons.update();

  Serial.print("Temperature = ");
  Serial.print(temperature);
  Serial.println(" °C");

  // Convertir a Fahrenheit y Kelvin
  double fahrenheit = (temperature * 9.0 / 5.0) + 32.0;
  double kelvin = temperature + 273.15;

  if (carrier.Buttons.onTouchDown(TOUCH0)) {
    printTemperature(temperature, "C");
    printTemperature(fahrenheit, "F");
    printTemperature(kelvin, "K");
  }
}

void printTemperature(double temp, const char *unit) {
  carrier.display.fillScreen(ST77XX_RED);
  carrier.display.setTextColor(ST77XX_WHITE);
  carrier.display.setTextSize(6);
  carrier.display.setCursor(30, 50);
  carrier.display.print("Temp: ");
  carrier.display.setTextSize(4);
  carrier.display.setCursor(40, 120);
  carrier.display.print(temp);
  carrier.display.print(" ");
  carrier.display.print(unit);
}
``` 
### Ejercicio #3
### **Uso del sensor PIR y cambio de pantalla con respecto a la temperatura.**
En la fase final de nuestro proyecto, implementamos el sensor de movimiento PIR, conectado a la puerta analógico 5. Cuando el sensor detecta movimiento, activa el zumbador integrado en el sistema. Además, al detectar movimiento, también cambie el color del display. Cuando la temperatura registrada es baja, se ilumina en azul para indicar frío, mientras que cuando la temperatura aumenta, el color cambia a rojo para indicar calor.

En conclusión, aunque nos gustaría mostrar el resultado final de esta configuración completa, lamentablemente, debido a restricciones de tiempo, no podemos hacerlo en este momento. Sin embargo, nos aseguraremos de que el código esté correctamente implementado para cumplir con los requisitos de funcionamiento establecidos. 

**Código:**
``` cpp
#include <Arduino_MKRIoTCarrier.h>
MKRIoTCarrier carrier;
double temperature = 0;
float humidity = 0;
int pir = A5; // Pin del sensor PIR
bool pirState = LOW;

void setup() {
  Serial.begin(9600);
  CARRIER_CASE = true;
  carrier.begin();
}

void loop() {
  temperature = carrier.Env.readTemperature();
  humidity = carrier.Env.readHumidity();
  carrier.Buttons.update();

  pirState = digitalRead(pir);

  if (pirState == HIGH) {
    activateLights();
    printTemperature();
  }
  delay(1000); 
}

void printTemperature() {
  if (temperature < 25) {
    carrier.display.fillScreen(ST77XX_BLUE); 
  } else {
    carrier.display.fillScreen(ST77XX_RED);
  }

  carrier.Buzzer.sound(500);
  delay(1000);
  carrier.Buzzer.noSound(); 

  carrier.display.setTextColor(ST77XX_WHITE); // Texto
  carrier.display.setTextSize(6); 

  carrier.display.setCursor(30, 50);
  carrier.display.print("Temp: ");
  carrier.display.setTextSize(4); 
  carrier.display.setCursor(40, 120); 
  carrier.display.print(temperature);
  carrier.display.print(" C");
}

void activateLights() {
  // Iluminar los LEDs de color blanco
  carrier.leds.setPixelColor(0, 255, 255, 255); 
  carrier.leds.setPixelColor(1, 255, 255, 255);
  carrier.leds.setPixelColor(2, 255, 255, 255);
  carrier.leds.setPixelColor(3, 255, 255, 255);
  carrier.leds.setPixelColor(4, 255, 255, 255); 
  carrier.leds.show();
}

``` 

## Conclusión 

Logramos completar la mayoría de las tareas, sin embargo, algunas no pudimos terminar debido a la falta de tiempo. En cuanto a los comentarios, enfrentamos dificultades con la descarga de bibliotecas y la conexión. A pesar de esto, hemos recopilado todo lo aprendido para poder seguir avanzando y mejorando en nuestras actividades futuras. Brindandonos la posibilidad de controlar y monitorear dispositivos de forma remota, lo que nos ofrece beneficios significativos en términos de sistematizado, optimizado y con una facilidad.

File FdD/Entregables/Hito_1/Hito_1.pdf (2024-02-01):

ECOBURNMONITOR; Proyecto

Monitor de quema de combustible contaminante

# Integrantes

Daniel Hermosa Quispe

### Jander Huamani Salazar

Said Quispe Diaz
Milagros Acevedo Valer

# Coordinador general

# Manufactura

# Encargada del diseño de software (Full - Stack)

# Encargado del área de electronica

# Encargado de Investigación y experiencia del cliente

# Contenido

CONTEXTO SOCIAL Y ECONÓMICO; IDENTIFICACIÓN DEL PROBLEMA; CONTEXTO CIENTIFICO Y COMERCIAL; INTRODUCCIÓN; LISTA DE REQUERIMIENTOS; MATRIZ MORFOLÓGICA Y TABLA DE VALORACIÓN; PROYECTOS PRELIMINARES; MATRICES DE EVALUACIONES: TÉCNICA Y ECONÓMICA

CASO DE ESTUDIO

CAJA NEGRA Y
ESQUEMA DE FUNSIONES

# Caso de Estudio

del impacto

Escases de datos necesarios para la evaluación
del uso de combustibles fósiles para preparar los
alimentos en el departamento de Huancavelica

CONTEXTO SOCIAL Y; ECNÓMICO

# Contexto Social


# Nivel Mundial

# cerca del 29% de la población mundial (2. 300 millones) siguen utilisando combustibles fósiles para preparar sus

alimentos.

# Nivel Nacional

# En el Perú, solo el 5% de la matriz energética del perú viene de energia renovables Ademas, solo hay registros de la calidad del aire en Lima Metropolitana, el resto del pais no cuenta con dichas estadisticas

ONU (2023). En Informe de los Objetivos de desarrollo sostenible. Unstats.un.org. Recuperado el 15 de enero de 2024

Mundial; En America Latina, cerca del 11% de la población aún requieren del uso de combustibles fosiles para la preparación de sus alimentos; El aumento en sus precios durante el 2022 resultaron en mayores costos para los consumidores domésticos y las empresas. Esto se traduce en gastos adicionales para la calefacción, la cocina y la producción de bienes y servicios, afectando los presupuestos tanto a nivel individual como empresarial; America Latina; Contexto Económico

Minem (2019).Energías renovables representan el 5% de la matriz energética del Perú. Gob.pe. Recuperado el 15 de enero de 2024 INEI (2020) Precios al consumidor en Lima Metropolitana aumentaron 0,52% en noviembre de 2020. Gob.pe. Recuperado el 15 de d

Identificación del problema

# Mapa de Empatía


-Datos de monitoreo
ambiental que indiquen
la calidad del aire en
diferentes regiones

-Informes sobre
emisiones y su impacto
en la salud pública y el
medio ambiente

-Informes y estudios
científicos sobre la
relación entre la
contaminación del aire y
la salud

-Conversaciones sobre la
necesidad de medidas
más estrictas para
reducir emisiones

-Preocupaciones sobre
los efectos a largo plazo
de las emisiones de
combustibles fósiles.

-Responsabilidad hacia
la salud pública y la
preservación del medio
ambiente.

-Desarrollo e
implementación de
políticas ambientales

-Colaboración con
hospitales y otras
instituciones para abordar la contaminación del aire

-Frustración por no tener
datos más específicos
sobre las emisiones en el
aire

-Preocupación por la
falta de conciencia
pública sobre los
impactos de la
contaminación del
aire

-Necesidad de datos
actualizados y
precisos para mejores
soluciones

-Deseo de
implementar medidas
que reduzcan las
emisiones y mejoren
la calidad del aire
Ramos, I. (2019, 31 de agosto). "Somo pobres": Así es tener que cocinar con leña por obligación. https://www.radiofeyalegrianoticias.com/asi-es-tener-que-cocinar-con-lena-por-obligacion/

Los datos sobre los efectos perjudiciales de la quema de combustibles fósiles para preparar los

La escases de datos limitan la información necesaria y retrasan el desarrollo de proyectos para solucionar una problemática que afecta en

*Se evidencia un ahorro económico en las familias, ya que el consumo de leña se ha reducido

Wong, E. (2022). Implementación de cocinas mejoradas a leña y disminución de GEI. Ingeniería Investiga, 4, e712. https://doi.org/10.47796/ing.v4i0.712

# Mapa de Ishikawa


Escasez de datos
sobre la incidencia
de enfermedades
respiratorias
causadas por gases
tóxicos y material
particulado en la
ciudad de
Huancavelica.

Ramos, I. (2019, 31 de agosto). "Somos pobres": Así es tener que cocinar con leña por obligación. https://www.radiofeyalegrianoticias.com/asi-es-tener-que-

cocinar-con-lena-por-obligacion/

# Definición del problema

En Huancavelica, la mayoría de la población (76,9%) depende de combustibles fósiles para cocinar debido a limitaciones financieras. Esta práctica genera graves riesgos para la salud, como problemas respiratorios por la exposición al CO2 y partículas PM2.5, afectando tanto a los habitantes como al medio ambiente. La falta de información precisa sobre las emisiones de CO2 agrava los desafíos para el sistema de salud en Huancavelica. Gráfico en porcentajes. Tomada de (INEI,2021)

Instituto Nacional de Estadística e Informática (INEI). (diciembre de 2022). Libro estadístico.https://www.inei.gob.pe/media/MenuRecursivo/publicaciones_digitales


# CONTEXTO CIENTÍFICO

## (1) Revisión sistemática cuyo objetivo principal es dar una visión general del

## campo de monitoreo y su estado actual

(2) Describe el desarrollo de un sistema de monitoreo de calidad del aire que es a la vez asequible y portátil, basado en la plataforma Arduino
Karami, M., McMorrow, G. V., & Wang, L. (2018). Continuous monitoring of indoor environmental quality using an Arduino-based data acquisition system. Journal of Building Engineering
Saini, Jagriti, Maitreyee Dutta, and Gonçalo Marques.( 2020). "Indoor Air Quality Monitoring Systems Based on Internet of Things: A Systematic Review" International

Índice de calidad de aire por; material; particulado; enfermedades respiratorias en el centro poblado de Callqui Chico-Huancavelica, 2021

Chen, J., & Hoek, G. (2020). Long-term exposure to PM and all-cause and cause-specific mortality: A systematic review and meta-analysis. Environment international Paredes Ccente, D. C., & Quispe Martinez, D. M. (2022, 1 de julio). Índice de calidad de aire por material particulado y enfermedades respiratorias en el centro poblado de Callqui Chico-Huancavelica, 2021 .Repositorio Institucional de la Universidad Nacional de Huancavelica.

# CONTEXTO COMERCIAL

Dispositivos y/o Equipos | Patenetes


Sensor MK CO

Medidor portatil GM70

Medidor de partículas PC

- QD 20

Opciones de
respiración para el
análisis.

Sistemas y métodos para la recopilación de datos
autoorganizada basados en
parámetros del entorno de

producción.

Cella, C. H., Duffy, G. W. Jr., McGuckin, J. P., & Desai, M. (2020). Methods for self-organizing data collection and storage (No. US20200089211A1). Oficina de Patentes y Marcas de los Estados Unidos.
Wondka, A. D., Wondka, A. D., Batnagel, A., Batnagel (2020). Breathing choices for analysis (No. JP6787969B2). Oficina de Patentes de Japón.

F

u

Tabla; de Requerimientos; cir; mitir; Din; mic; sib; fia; bilid; rid

# Caja Negra y Esquema de

# Funciones


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
# gia

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
# alid

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
# vis

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
# CajCaajaNNeeggra ra

### Entradas

Transformar; Energía; Transducir; Procesar; Almacenar; Transmitir; Información en plataforma(datos obtenidos ,promedios); Alarma sonora/visua l(90 db); Salidas; Leyenda; Energia; Información; su uso; Descripción de funciones

Proporciona el voltaje requedido para

Los sensores que están conectados al arduino
trasnduciran las concentraciones que nos dan

Procesa los datos obtenidos por los sensores y

se envían a la base de datos

Los datos recopilados pasaran por operaciones
matemáticas automatizadas para su visualizacion de datos.

Se emitirá un aviso cuando las
concentraciones de los C.G superen
el límite estándar saludable
establecido por la OMS

T

M
a

a
b

t
la

# riz Morfológica y de Valoración

Opción 1; Opción 2; Opcion 3; Transformar; Regular; Almacenar; Sensor (CO2); Sensor (CO); Sensor (PM2.5); Transmitir; Panel solar 3v 4.7 x 6.4 cm pl-3v opalux; 0.5w 5v 100ma Mini Módulo De Panel Solar Pequeño Diy; Panel Solar 5,5V PL-5-5V OPALUX; MÓDULO CARGADOR DE BATERÍA LITIO USB TC4056A CON STEP-UP REGULABLE; Tp4056 Modulo Cargador Bateria Litio 3.7v Micro Usb; Porta pilas+bateria de litio(2); Batería recargable polimero LIPO 3.7V 1400mAh; Dsm501a; Pantalla Lcd Tft +Buzzer; Procesar; Módulos de datos; Base de datos; Visualisación; Precio total; Controlador PWM LCD 10A 12/24V Must Solar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

Opción 1 | Opción 2 | Opcion 3

S/. 69

Firebase | Superbase

### AWS

ARDUINO
UNO S/.125

NodeMCU
S/. 30

ESP32
S/.140

Arduino Mega
S/. 120

ESP8266

CS 3 | CS 2 | CS 1
S/. 299,40 | S/. 649,7 | S/. 784,86

# Cool idea!

N

°

cilid; bla; bilid; rid; Dis; nibilid; ció

# CConnccluussióónn

plazo.; 3.7v Micro Usb; Porta pilas+bateria de; litio(2); Firebase; Buzzer+ leds(3) +interruptor; Arduino Mega; NodeMCU

Tp4056 Modulo
Cargador Bateria Litio

0.5w 5v 100ma Mini Módulo
De Panel Solar Pequeño Diy

Elegimos la tercera opción por ser más
económica, lo que la hace accesible a un
mayor número de usuarios. La
disponibilidad de repuestos también pesó
en nuestra decisión. Esta alternativa no
solo ahorra dinero a los usuarios, sino
que también ofrece mayor comodidad y
facilidad en el mantenimiento a largo

# Proyectos Preliminares y Matrices de Evaluación


Proyecto preliminar N°1 | Piezas | Nombre | Material
Transformador | panel solar 12v | Celulas solares de tipo policristalino
Regulador | módulo TP405 | Litio, cobre, PCB
Almacenamiento | porta pilas y 2 baterías de litio | metal inoxidable, lítio
Sensor (CO2) | MQ135 | NDIR (detector infrarrojo no dispersivo)
Sensor (CO) | MQ-7 | Detección de gas semiconductor
Sensor (pm2.5) | GP2Y1010AU0F GP2Y1014 | metal inoxidable, lítio
Avisar | Buzzer+leds(3)+interrup tor | Buzzer: Metal inoxidable Leds:plastico
Procesador | Arduino Mega | PCB, fibra de vidrio, Cobre
Módulo de datos | NodeMCU | PCB

Lista de despiece

Proyecto preliminar N°2 | Número | Nombre | Material
1 | panel solar (salida de 6V) | Silicio cristalino
2 | soporte para panel solar | Acero
3 | cables (2) | cobre
4 | MQ-7 | semiconductor sensible al CO
5 | GP2Y1010AU0F GP2Y1014 | litio, metal inoxidable
6 | MQ-135 | NDIR (detector infrarrojo no dispersivo)
7 | Leds (3) | plástico, cobre
8 | Armazón | madera
9 | soportes | metal
10 | Buzzer | metal , plastico
11 | Interruptor | plastico
12 | Módulo TP4056 | componentes electrónicos
13 | Cables | cobre
14 | porta pilas+pilas de litio (2) | plástico, pilas
15 | vooltage booster | componentes electrónicos
16 | Arduino mega | componentes electrónicos
17 | ESP8266 | componentes electrónicos

Lista de despiece

# Proyecto preliminar N°3

### Lista de despiece


N° | Nombre | Material
1 | panel solar (salida de 6V) | Silicio cristalino
2 | cables | cobre
3 | MQ-7 | semiconductor sensible al CO
4 | GP2Y1010AU0F GP2Y1014 | metal inoxidable, detector analógico de PM
5 | MQ-135 / MH-Z19B | NDIR (detector infrarrojo no dispersivo)
7 | Leds (3) | plástico, cobre
10 | Buzzer | metal , plastico
11 | Interruptor | plastico
12 | Módulo TP4056 | componentes electrónicos
14 | porta pilas+pilas de litio (2) | plástico, pilas
15 | ESP8266 | componentes electrónicos

# Proyecto preliminar N°4

### Lista de despiece

N° | Nombre | Material
1 | panel solar (salida de 6V) | Silicio cristalino
2 | cables + canaletas | cobre y plástico
3 | MQ-7 | semiconductor sensible al CO
4 | GP2Y1010AU0F GP2Y1014 | metal inoxidable, detector analógico de PM
5 | MQ-135 / MH-Z19B | NDIR (detector infrarrojo no dispersivo)
7 | Leds (3) | plástico, cobre
10 | Buzzer | metal , plastico
11 | Interruptor | plastico
12 | Módulo TP4056 | componentes electrónicos
13 | porta pilas+ baterias de litio (2) | plástico, pilas
14 | ESP8266 + Arduino Mega | componentes electrónicos

# Matriz de Evaluación Técnica

Evaluacion tecnica
VARIANTES DE PROYECTOS | | | Proyecto preliminar 1 | | Proyecto preliminar 2 | | Proyecto preliminar 3 | | Proyecto preliminar 4 | | Proyecto ideal
N° | Criterios de evaluación | G | P | GP | P | GP | P | GP | P | GP | P | GP
1 | Seguridad | 8 | 2 | 16 | 3 | 24 | 3 | 24 | 3 | 24 | 4 | 32
2 | Diseño | 6 | 4 | 24 | 3 | 18 | 3 | 18 | 3 | 18 | 4 | 24
3 | Ergonomía | 3 | 4 | 12 | 3 | 9 | 4 | 12 | 3 | 9 | 4 | 12
4 | Mantenimiento | 8 | 3 | 24 | 3 | 24 | 3 | 24 | 3 | 24 | 4 | 32
5 | Peso | 7 | 3 | 21 | 2 | 14 | 4 | 28 | 1 | 7 | 4 | 28
6 | Eficacia | 7 | 4 | 28 | 4 | 28 | 3 | 21 | 3 | 21 | 4 | 28
7 | Montaje | 8 | 3 | 24 | 3 | 24 | 3 | 24 | 2 | 16 | 4 | 32
8 | Fabricación | 6 | 2 | 12 | 2 | 12 | 3 | 18 | 4 | 24 | 4 | 24
Puntaje máx Σp o Σpg | | | 25 | 161 | 23 | 153 | 26 | 169 | 22 | 143 | 32 | 212
Valor técnico Xi | | | | 0,759 | | 0,722 | | 0,797 | | 0,675 | | 1
Orden | | | | 2 | | 3 | | 1 | | 4


Criterios de
evaluación
Descripción
Seguridad

D

Protección tanto fisica y en sofware iseño

Ergo

Nivel de tamaño y compactivilidad nomía
Mant

Nivel de comodidad para el cliente enimiento

Peso

Cuidados necesarios para el buen funcionamiento del dispositivo

Efica

Que tan pesado o liviano es el prototípo cia

Mon

Velocidad de detección y de envio de datos taje
Facilidad para ensamblar
Fabricación
Que tan riburoso es su construcción en fábrica

# Descripción de MET

# Matriz de Evaluación Económica

económica

VARIANTES DE PROYECTOS | | | Proyecto preliminar 1 | | Proyecto preliminar 2 | | Proyecto preliminar 3 | | Proyecto preliminar 4 | | Proyecto ideal
N° | Criterios de evaluación | G | P | GP | P | GP | P | GP | P | GP | P | GP
1 | Costo de materiales | 8 | 4 | 32 | 3 | 24 | 3 | 24 | 4 | 32 | 4 | 32
2 | Costo de fabricación | 7 | 3 | 21 | 2 | 14 | 3 | 21 | 3 | 21 | 4 | 28
3 | Costo energético | 7 | 3 | 21 | 4 | 28 | 3 | 21 | 3 | 21 | 4 | 28
4 | Costo de mantenimiento | 8 | 3 | 24 | 3 | 24 | 2 | 16 | 3 | 24 | 4 | 32
5 | Disponibilidad de los materiales | 9 | 4 | 36 | 4 | 36 | 4 | 36 | 4 | 36 | 4 | 36
Puntaje máx Σp o Σpg | | | 17 | 134 | 16 | 126 | | 118 | 17 | 134 | 20 | 156
Valor técnico Yi | | | | 0,859 | | 0,808 | | 0,756 | | 0,859 | | 1
Orden | | | | 1 | | 2 | | 3 | | 1


Criterios de evaluación Descripción

Costo de materiales Que tan costoso son los componenetes del prototipo

Costo de fabricación Que tan costoso es el ensamblamiento del prototipo

Costo energético Que tanta energia consume el dispositivo

Costo de mantenimiento
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
otoso es el mantenimiento del prototipo para su optimo

Disponibilidad de los materiales Que tan accesibles son el encontrar los compomentes del prototipo

# Descripción DE MEE

# Proyecto Óptimo

N° Proyecto Preliminar | Valor técnico Xi | Valor técnico Yi
Proyecto preliminar 1 | 0,759 | 0,859
Proyecto preliminar 2 | 0,722 | 0,808
Proyecto preliminar 3 | 0,797 | 0,756
Proyecto preliminar 4 | 0,675 | 0,859

Conclusion

Tras realizar tanto la matriz teórica

como la matriz económica, el proyecto

preliminar N°1 recaudó el mayor

puntaje tanto en teórico(0.809) como

en económico(0.859), por lo que

optamos que el proyecto preliminar

N°1 es nuestro proyecto ganador.

# Rferencias Bibliográficas

Agencia de Protección Ambiental de los Estados Unidos (EPA). (10 de mayo de 2023). Efectos del material particulado (PM) sobre la salud y el medioambiente. Recuperado de https://espanol.epa.gov/espanol/efectos-del-material-particulado-pm-sobre-la-salud-y-el-medioambiente (https://espanol.epa.gov/espanol/efectos-del-material-particulado-pm-sobre-la-salud-y-el-medioambiente)

Ayala, E. (2022, 12 de septiembre). Cocinar con leña: una práctica que nos daña tanto como el humo de los autos. Recuperado de https://saludconlupa.com/climatopedia/cocinar-con-lena-una-practica-que-nos-dana-tanto-como-el-humo-de-los-autos/

Bibliografía Acceso a tecnologías y combustibles limpios para cocinar (% de la población) - Latin America & Caribbean, Peru. (s/f). World Bank Open Data. Recuperado el 15 de enero de 2024, de https://datos.bancomundial.org/indicador/EG.CFT.ACCS.ZS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 (https://datos.bancomundial.org/indicador/EG.CFT.ACCS.ZS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)

Ecología Verde. (3 de abril de 2019). El impacto medioambiental del dióxido de carbono. Recuperado de https://www.ecologiaverde.com/el-impacto-medioambiental-del-dioxido-de-carbono-1334.html (https://www.ecologiaverde.com/el-impacto-medioambiental-del-dioxido-de-carbono-1334.html)

Escobar, R., Gamio, P., Moreno, A. I., Castro, A. S., Cordero, V., & Vásquez, U. (2016). Energización rural mediante el uso de energías renovables para fomentar un desarrollo integral y sostenible: Propuestas para alcanzar el acceso universal a la energía en el Perú. Recuperado el 15 de enero de 2024, de https://repositorio.pucp.edu.pe/index/bitstream/handle/123456789/64216/varios_propuestas_acceso_energia.pdf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 (https://repositorio.pucp.edu.pe/index/bitstream/handle/123456789/64216/varios_propuestas_acceso_energia.pdf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)

Global, G. (2022, marzo 25). Precio del gas natural en los mercados internacionales. Recuperado de https://gnlglobal.com/precio-del-gas-natural-en-los-mercados-internacionales/ (https://gnlglobal.com/precio-del-gas-natural-en-los-mercados-internacionales/)

# Rferencias Bibliográficas

INEI (Instituto Nacional de Estadística e Informática). (diciembre de 2022). Libro estadístico. Recuperado de I (https://www.inei.gob.pe/media/MenuRecursivo/publicaciones_digitales/Est/Lib1881/libro.pdf)
Minem. (2019). Energías renovables representan el 5% de la matriz energética del Perú. Recuperado el 15 de enero de 2024, de https://www.inei.gob.pe/media/MenuRecursivo/publicaciones_digitales/Est/Lib1881/libro.pdf

Minem. (2019). Energías renovables representan el 5% de la matriz energética del Perú. Recuperado el 15 de enero de 2024, de https://www.minem.gob.pe/_detallenoticia.php?idSector=9&idTitular=9581

New Jersey Department of Health. (julio de 2016). Lead in Water: Reducing Lead Exposure - Spanish. Recuperado de https://www.nj.gov/health/eoh/rtkweb/documents/fs/0343sp.pdf

Novogas. (2023, 3 de julio). Más de un millón de hogares cocinan con leña en el Perú. Recuperado de https://www.linkedin.com/pulse/m%C3%A1s-de-un-mill%C3%B3n-hogares-cocinan-con-le%C3%B1a-en-el-per%C3%BA-novogaslatam/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 (https://www.linkedin.com/pulse/m%C3%A1s-de-un-mill%C3%B3n-hogares-cocinan-con-le%C3%B1a-en-el-per%C3%BA-novogaslatam/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)

ONU. (2023). Informe de los Objetivos de desarrollo sostenible. Recuperado el 15 de enero de 2024, de https://unstats.un.org/sdgs/report/2023/The-Sustainable-Development-Goals-Report-2023_Spanish.pdf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. (https://unstats.un.org/sdgs/report/2023/The-Sustainable-Development-Goals-Report-2023_Spanish.pdf)

Peru - Countries & Regions (s/f). IEA. Recuperado el 15 de enero de 2024, de https://www.iea.org/countries/peru

Gracias!

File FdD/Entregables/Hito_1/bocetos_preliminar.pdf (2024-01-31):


Piezas | Nombre | Material
Transformador | panel solar 12v | Celulas solares de tipo policristalino
Regulador | módulo TP405 | Litio, cobre, PCB
Almacenamiento | porta pilas y 2 baterías de litio | metal inoxidable, lítio
Sensor (CO2) | MQ135 | NDIR (detector infrarrojo no dispersivo)
Sensor (CO) | MQ-7 | Detección de gas semiconductor
Sensor (pm2.5) | GP2Y1010AU0F GP2Y1014 | metal inoxidable, lítio
Avisar | Buzzer+leds(3)+interruptor | Buzzer: Metal inoxidable Leds:plastico
Procesador | Arduino Mega | PCB, fibra de vidrio, Cobre
Módulo de datos | NodeMCU | PCB

## Título del proyecto:

## Dibujado por: Quispe Diaz Said Andre

## Boceto en conjunto

Por su forma cilíndrica esta pensado para posicionarse en superficies lisas. el sensor en cuestión presenta pequeñas aperturas rectangulares donde el humo entrará y saldrá, por encima de las aperturas, de manera interna, irán los detectores de CO2, CO y PM2.5 y Buzzer +leds(3)+interrupor.

En la base del dispositivo irá el procesador junto con el módulo de datos, al excederse cierta concentración de cualquiera de los 3 componentes a medir, el dispositivo emitirá un aviso audio visual para alertar al cliente y
tome las medidas necesarias para actuar

## Lista de despiece

## Proyecto preliminar 1


Número | Nombre | Material
1 | panel solar (salida de 6V) | Silicio cristalino
2 | soporte para panel solar | Acero
3 | cables (2) | cobre
4 | MQ-7 | semiconductor sensible al CO
5 | GP2Y1010AU0F GP2Y1014 | litio, metal inoxidable
6 | MQ-135 | NDIR (detector infrarrojo no dispersivo)
7 | Leds (3) | plástico, cobre
8 | Armazón | madera
9 | soportes | metal
10 | Buzzer | metal , plastico
11 | Interruptor | plastico
12 | Módulo TP4056 | componentes electrónicos
13 | Cables | cobre
14 | porta pilas+pilas de litio (2) | plástico, pilas
15 | vooltage booster | componentes electrónicos
16 | Arduino mega | componentes electrónicos
17 | ESP8266 | componentes electrónicos

## Título del proyecto:

## Dibujado por: Hermoza Quispe Daniel Rodrigo

## Boceto en conjunto

Descripción: | Lista de despiece
Por la forma del prototipo esta pensado
situarse en una esquina de la cocina , a
una altura media, los sensores irán en las
esquinas de la habitación . El equipo presenta 3 leds que presentan un indicador semáforo y esta equipado con un buzzer, estos tienen la función de dar un aviso al usuario cuando las concentraciones sobrepasen sus límites. Tiene dos soportes que irán apoyados a la pared. Por dentro irá el porta pilas con las pilas de litio, Arduino mega y el ESP8266. Con respecto al panel solar estará posicionado en el techo de la casa apoyado en un soporte.

## Proyecto preliminar 2


N° | Nombre | Material
1 | panel solar (salida de 6V) | Silicio cristalino
2 | cables | cobre
3 | MQ-7 | semiconductor sensible al CO
4 | GP2Y1010AU0F GP2Y1014 | metal inoxidable, detector analógico de PM
5 | MQ-135 / MH-Z19B | NDIR (detector infrarrojo no dispersivo)
7 | Leds (3) | plástico, cobre
10 | Buzzer | metal , plastico
11 | Interruptor | plastico
12 | Módulo TP4056 | componentes electrónicos
14 | porta pilas+pilas de litio (2) | plástico, pilas
15 | ESP8266 | componentes

## Dibujado por: Acevedo Valer, Milagros Soledad

## Boceto en conjunto

Descripción: | Lista de despiece
El prototipo está diseñado para ser
empotrado en la pared, a una altura
estándar de la cocina. El equipo constará
de tres LED o un LED de barra que servirán como indicador de semáforo, además de un zumbador para complementar su función. Estos componentes alertarán al usuario cuando las concentraciones de CO, CO2 y PM2.5 superen los límites establecidos. Su diseño ergonómico y compacto garantiza un uso eficiente del espacio. Internamente, incluirá un portapilas con pilas de litio, un Arduino Mega y un módulo para la transmisión de datos al NodeMCU. Además, contará con sensores para medir las concentraciones de CO, CO2 y PM2.5 en el aire.
El panel solar estará ubicado en el techo de la casa, asegurado firmemente al tejado de la vivienda.


N° | Nombre | Material
1 | panel solar (salida de 6V) | Silicio cristalino
2 | cables + canaletas | cobre y plástico
3 | MQ-7 | semiconductor sensible al CO
4 | GP2Y1010AU0F GP2Y1014 | metal inoxidable, detector analógico de PM
5 | MQ-135 / MH-Z19B | NDIR (detector infrarrojo no dispersivo)
7 | Leds (3) | plástico, cobre
10 | Buzzer | metal , plastico
11 | Interruptor | plastico
12 | Módulo TP4056 | componentes electrónicos
13 | porta pilas+ baterias de litio (2) | plástico, pilas
14 | ESP8266 + Arduino Mega | componentes

## Dibujado por: Huamani Salazar, Jander

## Boceto en conjunto

Descripción: | Lista de despiece
Este prototipo cuenta con dos conexiones,
ambas seran mediante cables y canaletas
para que se vean mas estéticos. La
primera sera del panel solar a una caja de plástico con tapa removible la cual ira en la pared. en el interior de la caja se fijará el módulo TP4056, las baterias en la parte mas cercana a la tapa ; en el exterior se adherira a la caja el buzzer, los leds de colores(verde, amarillo y rojo) y el interruptor. Para finalizar se continuará con la conexión hacia una caja de plástico mas grande que tendra en la parte inferior una tapa de acero inoxidable con huecos para la entrada y salida de aire; la caja en su interior

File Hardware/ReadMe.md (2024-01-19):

# Información de Carpeta _Hadware_
Descripción de la parte física de nuestro proyecto, los conceptos básicos del hardware desde la etapa de planificación inicial hasta la finalización de la patente. La documentación archivada incluye evidencia detallada de modelado 3D, informes de pruebas de prototipos y otros datos relevantes que cubren varios hitos importantes para el sistema. Estos documentos respaldan todas las etapas críticas del desarrollo y optimización del producto, así como la fabricación y el diseño iniciales.

### Índice: 

* Prototipos
* Modelos 3D

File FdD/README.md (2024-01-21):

# Fundamento de Diseño 
Tiene como objetivo desarrollar en el estudiantecompetencias para diseñar, implementar, verificar, patentar y operar proyectos deinnovación. Comprende el siguiente contenido: identificar la necesidad o problema, crearconceptos de solución, implementar la solución, comunicar los resultados.

## Tabla de contenidos:

1. [Contenido/Entregables](#Contenido)
    - [Unidad 1](#Unidad-1)
      1. Entregables        
         1. [Sobre Nosotros](Entregables/1.Sobre_nosotros.md)          
         2. Problemática   
            * [Diagramas](Entregables/2.1Conectando_con_nuestros_usuarios.md)     
            * [Problematica](Entregables/2.2Def_prob.md)                 
         3. [Contexto Social y Economico](Entregables/3.Contexto_SyE.md)                
         4. [Estado del Arte(Contexto comercial y científico)](Entregables/4.Estado_del_arte.md)         
         5. Metodología de diseño 
            * [Caja negra y esquema de funciones](Entregables/5.CajaNegra_y_esq_defunciones.md)
      2. Talleres
         * [Informacion sobre equipos](Talleres/1.Informe_equipolab.md)
      3. Hitos
         * Hito 1
         * Hito 2
    - [Unidad 2](#Unidad-2)
    - [Unidad 3](#Unidad-3)
2. [Evaluación](#Evaluación)
3. [Docentes](#Docentes)

## Descripción 
_En este curso se presenta a los estudiantes desafíos reales basados en problemáticasambientales dentro del contexto nacional. Se le brindará al estudiante conocimientos, comoel uso de dispositivos IoT e impresión 3D que le permitan crear soluciones a los problemasidentificados. Haciendo uso de las metodologías del diseño determinístico y designthinking, el alumno podrá identificar y analizar necesidades, diseñar conceptos de solucióny crear prototipos innovadores de baja resolución usando fabricación digital._

## Contenido:

#### Unidad 1
###### Identificación de la necesidad o problema:
    1.  Introducción al curso e introducción a Git y GitHub
    2.  Introducción al laboratorio. Presentación de situación problemática.
    3.  Identificación del problema
    4.  Repositorio en GitHub y presentación de los miembros del equipo.
    5.  Revisión bibliográfica
    6.  Introducción a los equipos de laboratorio
    7.  Revisión de patentes
    8.  Contexto social y económico
    9.  Introducción al diseño determinístico10. Descripción del problema identificado. 
#### Unidad 2
###### Creación de conceptos de solución:
    1. Metodología de diseño VDI 2221 y 2225
    2. Estado del arte (contexto comercial y científico) y lista de requerimientos.
    3. Fundamentos de electrónica
    4. Uso de protoboard, circuitos básicos y procura de componentes electrónicos
    5. Prototipado con Arduino
    6. Uso de Arduino nano 33 IoT
    7. Ejemplos de matriz morfológica
    8.  Caja negra y esquema de funciones
    9.  Técnicas para bocetado
    10.  Matriz morfológica y tabla de valoración
    11.  Hito 1: bocetos y proyecto ganador

#### Unidad 3:
###### Implementación de la solución:
    1. Introducción al modelo 3D
    2. Modelado 3D
    3. Planos y laminación de modelos 3D
    4. Modelado 3D de la propuesta
    5. Formatos para corte láser
    6. Planos de modelado 3D y archivos para impresión 3D o corte láser
    7. Diagrama de flujo
    8. Esquemático del circuito electrónico
    9. Presentación de avance prototipo y esquemático electrónico
    10. Elevator pitch
    11. Integración de hardware - software y resolución de errores
    12. Hito 2: presentación de prototipo y póste
    
## Evaluación 
<table>
    <thead>
        <tr>
            <th>Aspectos por evaluar</th>
            <th>Ponderación</th>
        </tr>
    </thead>
    <tbody>
        <tr>
            <td align="left ">Evaluación continua (EC)
<ul>
  <li>Informes (IF)............40%.</li>
  <li>Talleres (TA)............40%</li>
  <li>Autoevaluación (AE)......20%</li>
</ul>
</td>
            <td align="center">30%</td>
        </tr>
         <td align="left ">Hito 1 (H1)
<ul>
  <li>Ayuda visual (AV)........30%</li>
  <li>Presentación oral (PO)...50%</li>
  <li>Autoevaluación (AE.......20%)</li>
</ul>
</td>
            <td align="center">30%</td>
        </tr>
         <td align="left ">Hito 2 (H2)
<ul>
  <li>Póster (PS)..............20%</li>
  <li>Presentación oral (PO)...30%</li>
  <li>Prototipo (PR)...........30% </li>
  <li>Autoevaluación (AE)......20%</li>
</ul>
</td>
            <td align="center">40%</td>
        </tr>
        <tr>
            <td align=" right">Total</td>
            <td align="center">100%</td>
        </tr>
    </tbody>
</table> 

## Docentes
|  Nombres y Apellidos |  Correo electrónico |
|:---:|:---:|
| Umbert Lewis De la Cruz Rodriguez  | umbert.de.la.cruz@upch.pe  |
| Juan Manuel Zúñiga Mamani  | juan.zuniga@upch.pe  |
| Renzo José Chan Ríos  | renzo.chan@upch.pe  |

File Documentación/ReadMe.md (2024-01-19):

# Información 
En este apartado recopilaremos toda la información importante con relación a nuestro proyecto. Este repositorio de documentos cubre una amplia gama de aspectos clave, proporcionando una descripción general completa de las fuentes de información, la dirección estratégica y los datos subyacentes que guían cada fase del proyecto.

Desde el diseño hasta la implementación, la accesibilidad y la cuidadosa organización de este documento garantizan una referencia clara y coherente.

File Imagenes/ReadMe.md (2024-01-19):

# Introdución de la carpeta Imagenes
Contenido multimedia referente a nuestro proyecto.
En esta carpeta encontras conenido de multimedia sobre los integrantes, las investigacionces y prototipos del proyecto. Todas las imágenes en formato jpeg y png, con el objetivo de facilitar un diseño más eficiente e implementación más fluida. 

## Contenido 
Aún más contenido al seguir el transcurso de las clases.

|Entregables | Talleres |
|:---|:---|
|Intregrantes [☜](Informacion_de_integrantes)| Taller de Equipos 🔌|
|Contexto Social 🌎||
|Contexto Económico 📈|| 
|Diagramas y Problemática 📝||

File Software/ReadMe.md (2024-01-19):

 # <center>Introdución a la carpeta _Software_</center>
 Información sobre el desarrollo del sistema de nuestro proyecto, tanto back- end como frontd - end. Esta carpeta alberga archivos esenciales para el desarrollo y ejecución de programas en Python. Contiene scripts, módulos y proyectos que abarcan diversas funcionalidades. Organizada de manera estructurada, esta colección representa el núcleo de mi trabajo en el ámbito de la programación, ofreciendo soluciones eficientes y prácticas para una variedad de tareas y proyectos.

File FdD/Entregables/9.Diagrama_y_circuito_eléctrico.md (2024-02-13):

# Diagrama de flujo 
Diagrama sin título drawio
# Esquema eléctrico 
esquema_eleéctrico

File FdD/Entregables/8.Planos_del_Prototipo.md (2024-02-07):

# Planos del Prototipo

## Planos de los componentes


[Original](componente_delprototipo.pdf)
## Plano de la colocación de los sensores
svf

[Original](prototipo_delos_sensores.pdf)
## Visualizacion en el programa CURA
svf
svf

## Plano del almacenamiento
ESTUCHEfinal
tapaFinal

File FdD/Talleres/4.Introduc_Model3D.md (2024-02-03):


# <h1 align= "center"> **Introducción al modelado 3D**</h1>

### Integrantes:
* Said Andre Quispe Diaz
* Hermoza Quispe, Daniel Rodrigo
* Acevedo Valer, Milagros Soledad
* Jander Huamani Salazar

### Lista de contenido
1. [Introducción](#introducción)
2. [Objetivo](#objetivo) 
3. [Ejecución de la actividad](#ejecución-de-la-actividad)
    1. [Funciones](#funciones-utilizadas-y-su-breve-descripción)
    1. [Diseño de vaso](#diseño-de-vaso)
        * [Creación de cuenta](#creación-de-cuenta)
        * [Actividad 1](#actividad-1)
        * [Creación de nuevo plano](#creación-de-nuevo-plano) 
        * [Actividad 2](#actividad-2)
    2. [Diseño de base para Arduino Uno](#recreando-una-carcasa-para-el-arduino-uno)   
4. [Discusión](#discusión)
5. [Conclusión](#conclusión)

# Introducción
En los últimos años, el avance de la tecnología ha beneficiado de diversas formas en diversos ámbitos de nuestra sociedad, algunos ejemplos son: el uso de drones, el accesos a internet, los teléfonos inteligentes, prótesis médicas accesibles o las impresoras 3D.
Estas últimas han representado una opción viable para la fabricación de objetos en general como prótesis, juguetes, componentes, prototipos, etc. Sin embargo, para que la impresora empiece a fabricar, primero tenemos que enviarle el modelo vía virtual del objeto que queremos que se fabrique, para ello existen diversas plataformas cuyas herramientas nos permiten diseñar de forma intuitiva como la plataforma “Onshape” cuya ventaja sobre la competencia es que no tienes que pagar una suscripción para comenzar a diseñar.

<p align= "center">
<table class="default" align= "center">
  <tr>
    <td><p align= "center">Figura 1. Impresora 3D </p></td>
    <td><p align= "center">Figura 2. Diseño de OnShape </p></td>
  </tr>
</table></p>

## Objetivo:
En el presente taller, se instruirán sobre las bases aprendidas y algunos ejemplos sobre el uso de la plataforma Onshape para el modelado en 3D de diversos objetos para su próxima producción en impresoras 3D.Permitiendo familiarizarnos con herramientas de diseño 3D y desarrollar habilidades en modelado tridimensional. 
# Ejecución de la actividad
En esta actividad introductoria para el manejo básico de la plataforma Onshape, se abordan dos proyectos clave: el diseño de una base para Arduino Uno y la creación de un vaso. Mientras que el diseño de la base se centra en la funcionalidad y el soporte del dispositivo, el proyecto del vaso explora aspectos estéticos y creativos.
### Funciones utilizadas y su breve descripción:
- **Onshape:** es una plataforma de diseño asistido por computadora (CAD) basada en la nube que permite a los usuarios crear y colaborar en modelos 3D de manera simultánea, accesible desde cualquier dispositivo con conexión a Internet.
- **Extrude (Extrusión):** Operación que implica estirar un perfil bidimensional a lo largo de un eje para crear una forma tridimensional. En OnShape, se utiliza el color rojo para resaltar la geometría no finalizada en un boceto, indicando elementos que requieren ajustes.
- **Revolve (Revolución):** Operación que gira un boceto bidimensional alrededor de un eje para crear una forma tridimensional simétrica. En OnShape, el color azul indica que la geometría está bien construida, pero aún necesita estar completamente definida, como agregar cotas a los lados del boceto.
- **Filleting (Redondeo):** Operación que crea un borde biselado a partir de las aristas de un objeto para evitar esquinas afiladas. La geometría en negro indica que las líneas y la geometría están completamente definidas y resueltas, lista para operaciones de modelado posteriores.
- **Shell (Vaciado):** Operación que crea un espacio hueco o un agujero dentro de una pieza seleccionando una región para eliminar su volumen. En OnShape, se utiliza el color rojo para resaltar la geometría no finalizada, señalando áreas que necesitan ajustes.
- **Dimension (Cota):** Medida o conjunto de medidas que especifica las dimensiones de un objeto. En OnShape, el color azul indica que la geometría está bien construida pero necesita estar completamente definida, como agregar cotas precisas.
### Funciones adicionales:
- **Sweep (Perfil):** Crea una forma 3D moviendo un perfil 2D a lo largo de un camino especificado.
- **Loft (Creación de Sección Transversal):** Crea una forma mezclando entre dos o más perfiles transversales a lo largo de un camino definido.
- **Pattern (Patrón):** Replica características o cuerpos en un arreglo específico.
- **Mirror (Espejo):** Genera una copia reflejada de características o cuerpos seleccionados.
- **Boolean Operations (Operaciones Booleanas):** Combina o sustrae formas utilizando operaciones como unión, intersección o sustracción para crear geometría compleja.
- **Shell (Vaciado):** Crea espacios huecos o elimina material de un sólido, útil para aligerar o agregar características internas.

[Volver al inicio](#lista-de-contenido)

## Diseño de vaso
Para el presente taller utilizaremos un vaso como modelo 3D, hay diversas formas de modelar un vaso, mas para el taller indicaremos dos ejemplos .
### Creación de cuenta:
Antes de iniciar el diseño en la plataforma Onshape, es necesario crear una cuenta. Una vez creada la cuenta, procedemos a seleccionar la opción "Create" para generar un nuevo documento, donde comenzaremos de inmediato a diseñar nuestro modelo 3D.

<p align= "center">
</p><p align= "center">Imagen 1. Inicio de sección </p>

Si el usuario ya tiene una cuenta, simplemente debe hacer clic en "SIGN IN". Si aún no la tienes, dirígete a la opción "Create a Student Account" y sigue las indicaciones para activar tu cuenta. Continuando con la pantalla de inicio para la creación de los modelos 3D. 
<p align= "center">
</p><p align= "center">Imagen 2. Portafolio  </p>

Para crear un plano, simplemente ve a "Create", luego selecciona "Document..." y podrás comenzar a crear.
<p align= "center">
</p><p align= "center">Imagen 3. Programa de diseño </p>

### Actividad 1
En la parte superior derecha encontrará una un esquema que muestra las                 diversas caras del modelo, en este caso nos ubicamos en la cara “Top”. Seguidamente utilizamos la herramienta sketch, ubicada en la parte superior  izquierda, y seleccionamos la cara “top”, se hace esto para poder utilizar herramientas de diseño 2D solamente en 
dicha cara.
<p align= "center">
</p><p align= "center">Imagen 4. Plano de Top(Arriba) </p>

Ahora seleccionamos la herramienta “Center point circle” para crear un círculo, después seleccionamos la herramienta “Dimension” para darle la dimensión que nosotros queramos (cabe resaltar que nosotros utilizamos dimensiones en base a milímetros), en este caso, la dimensión establecida es  80mm.
<p align= "center">
</p><p align= "center">Imagen 5. Creación de circulo </p>

Tambien es importante mencionar los colores que presenta los lados de las figuras que creamos, si es de color azul, quiere decir que a la figura le faltan definiciones necesarias para su correcta impresión, si es de color rojo, querra decir que la figura presenta inconcruencias con los datos proporcionados y deben ser corregido, si es de color negro quiere decir que la figura en cuestión esta en condiciones óptimas.
<p align= "center">
</p><p align= "center">Imagen 6. Dimensiones</p>

Una vez establecida la dimensión, seleccionamos los centro del círculo y del cuadrado y seleccionamos la herramienta “concentric” ubicada donde se señala en la siguiente figura, una vez realizada la acción, podemos finalizar con el sketch dandole en el símbolo ✓.
<p align= "center">
</p><p align= "center">Imagen 7. Centrado</p>

Seleccionamos el círculo y utilizamos la herramienta “Extrude”, esta herramienta nos permite transformar nuestro diseño 2D en 3D, permitiéndonos también introducir la profundidad que nosotros queramos(en nuestro caso son 100mm).
<p align= "center">
</p><p align= "center">Imagen 8. De 2D a 3D</p>

Una vez establecida la profundidad, utilizaremos la herramienta “Shell” para formar el vacío de vaso, esta herramienta nos permite también establecer un grosor específico para los bordes (en nuestro caso son 3 mm). 
Luego utilizamos la herramienta “Fillet “ para crear bordes curvados y silos tanto en la parte superior como inferior como se muestra en la siguiente imagen.

<p align= "center">Imagen 9. Darle forma curvada</p>

Para ir finalizando nuestro vaso, ubicamos en la parte inferior izquierdo la palabra “part 1” damos clic derecho y seleccionamos la opción que dice “ edit apparence”, en dicha opción podemos cambiar el color de nuestro modelo, lo cual, además de estético, es útil al momento de diferenciar diversos diseños al momento de juntarlos en un solo documento.

<p align= "center">Imagen 10. Modelo final</p>

[Volver al inicio](#lista-de-contenido)

### Creación de nuevo plano
Antes de empezar con la actividad N°2, primero seleccionamos la herramienta “Insert new tab” ubicado en la parte inferior izquierda y damos clic en la opción “Create part studio”, esta nos abrirá un nuevo folder de diseño para así crear otro modelo 3D sin tener que modificar el anterior ya realizado.
<p align= "center"> Imagen 11. Crear uno nuevo</p>

### Actividad 2
A diferencia del ejemplo anterior, nos ubicamos en la cara denominada “front”, seleccionamos la herramienta “Sketch” y seleccionamos la cara mencionada anteriormente.
Luego utilizamos la herramienta “Line” y creamos los mostrado en la siguiente imagen.

<p align= "center"> Imagen 12. Uso del "Line"</p>

Después seleccionamos la herramienta “Dimension” y establecemos las siguientes medidas: Línea superior: 40mm , Línea lateral derecha: 100 mm, Línea inferior: 25 mm 

<p align= "center"> Imagen 13. Dimensiones </p>

Seleccionamos el centro del plano cartesiano y utilizamos la herramienta midpoint (ubicada como se muestra en la siguiente figura) esta herramienta nos permite centralizar la figura referente al centro seleccionado y con este paso concluimos con el apartado del “Sketch”.

<p align= "center"> Imagen 14. Centrado </p>

Escogemos la figura y usamos la herramienta “revolve” damos clic en “revolve axis” y seleccionamos el lado “y” del plano cartesiano, de esta forma se creará el paralelo de dicha figura.
Después utilizamos la herramienta “Shell” para crear el interior y los bordes vaso (3 mm) y posteriormente, utilizando la herramienta “Fillet” damos forma 
	bordes más lisos y curvos.

<p align= "center"> Imagen 15. Segundo modelo de vaso </p>

[Volver al inicio](#lista-de-contenido)

## Recreando una carcasa para el Arduino UNO
Con los conocimientos adquiridos, creamos una carcasa en 3D para el reposo del arduino uno; para su desarrollo se usaron algunos de los comandos vistos anteriormente, sketchs y principalmente las funciones, shell, dimensión y extrudir. 

<p align= "center"> Figura 3. Dimensiones del Arduino UNO </p>

Posteriormente después de finalizar con el modelado 3D, se envió el archivo en formato .STL al laboratorio de la universidad para su impresión. 

Imagen del diseño de una carcasa para el Arduino UNO:
|  |  |
|:--:|:---:|
|    |  |

[Volver al inicio](#lista-de-contenido)

## **Discusión**
En esta sesión se nos dificulto realizar con precisión el modelado en 3D debido a la poca experiencia de los participantes en el uso de estas plataformas de tipo (CAD), también consideramos el poco tiempo que tuvimos para realizar el modelado no nos favoreció y adicionalmente tardamos por que las dimensiones en internet del arduino uno se encontraban en diferentes unidades de medida. Sin embargo el equipo logró estar cerca del resultado y se pudo imprimir el trabajo hecho.

## **Conclusión**

Se llegó a la conclusión de que este taller nos proporcionó todas las herramientas y conocimientos necesarios para el modelado en 3D, además pudimos comprender y poner en práctica las principales funciones del OnShape, lo cual nos facilitará el modelado 3D para nuestro prototipo.

<p align= "center">Imagen 15. Impresiódel diseño  </p>

[Volver al inicio](#lista-de-contenido)

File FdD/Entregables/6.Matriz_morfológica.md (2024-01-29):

<h1 align="center">Matriz Morfológica y Evaluación de Conceptos de Solución</h1>

### Lista de contenido:
* [Tabla morfológica ](#Tabla_morfológica)
* [Tabla de valoración](#Tabla_de_valoración)
* [Conclusiones](#Conclusiones)
# Tabla morfológica 
morf1

morf3

# Tabla de valoración 
morf2

# Conclusiones 

Optamos por la alternativa número 3, ya que presenta un costo considerablemente más bajo. Elegimos esta opción para que sea accesible a un mayor número de usuarios, permitiéndoles disfrutar de sus beneficios sin que el factor económico sea una barrera significativa. Además, la facilidad en la disponibilidad de repuestos influyó en nuestra decisión. Esta opción no solo representa un ahorro financiero para los usuarios, sino que también una mayor practicidad y conveniencia en el mantenimiento a lo largo del tiempo.

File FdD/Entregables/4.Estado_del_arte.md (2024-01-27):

# <p align = "center"> 🖼Estado del arte🖌 </p>
Realizar una investigación de artículos científicos provenientes de fuentes verificadas que presenten resultados experimentales basados en hechos conocidos o nuevos conocimientos. Además, llevar a cabo la búsqueda de equipos o dispositivos existentes en el mercado y patentes que cumplan funciones relacionadas con la problemática. Para concluir, la elaboración de una tabla que contenga los requerimientos funcionales y no funcionales, para solucionar el problema.  
### Contenido:
1. Contexto Científico

   1.1 [Artículo #1](#artículo-1-indoor-air-quality-monitoring-systems-based-on-internet-of-things-a-systematic-review-sistemas-de-monitoreo-de-la-calidad-del-aire-interior-basados-en-internet-de-las-cosas-una-revisión-sistemática)

   1.2 [Artículo #2](#artículo-2-continuous-monitoring-of-indoor-environmental-quality-using-an-arduino-based-data-acquisition-system)

   1.3 [Artículo #3](#artículo-3-a-systematic-review-and-meta-analysis-of-field-studies-of-portable-air-cleaners-performance-user-behavior-and-by-product-emissions)

   1.4 [Artículo #4](#articulo-4-long-term-exposure-to-pm-and-all-cause-and-cause-specific-mortality-a-systematic-review-and-meta-analysisexposición-a-largo-plazo-a-pm-y-mortalidad-por-todas-las-causas-y-por-causas-específicas-una-revisión-sistemática-y-un-metanálisis)
2. Contexto Comercial
    
    2.1 [Equipos o Dispositivos en el mercado](#dispositivos-en-el-mercado-o-equipos)
    
    2.1 [Patentes](#patentes)
3. [Lista de Requerimiento](#requerimientos)
4. [Bibliografía](#bibliografía)

## CONTEXTO CIENTÍFICO🧪

### Artículo 1. Indoor Air Quality Monitoring Systems Based on Internet of Things: A Systematic Review                                         (Sistemas de monitoreo de la calidad del aire interior basados en Internet de las cosas: una revisión sistemática)  

El siguiente artículo es una revisión sistemática que proporciona información del estado actual de los sistemas de monitoreo de la calidad del aire interior (IAQ) basados en LOT y su principal objetivo es, mediante la información de estudios realizados en diversos países, el proporcionar una visión general del campo de monitoreo de la calidad del aire interior y de paso resaltar las dificultades técnicas de la actualidad para futuras investigaciones. 

<p align="center"><strong>Figura 1:</strong></p>
<p align="center">
  
</p>

#### Resultados

De los 40 estudios realizados, la temperatura, la humedad, el CO 2 , el CO, las PM 10 , las PM 2,5 y los VOC son los parámetros de IAQ monitoreados más comúnmente. Donde 26 utilizaron 33 tipos de sensores dedicados para la detección de IAQ.
El sensor más utilizado fueron los censores de la serie MQ, utilizados para la detección de de múltiples tipos de gases, sin embargo, la principal desventaja de la serie MQ es que requieren una calibración de campo, además de que las especificaciones de precisión no están detalladas en las hojas de datos del fabricante
Solo dos estudios utilizaron placas de sensores todo en uno, cuya ventaja es que pueden medir múltiples parámetros con sondas de sensor precalibradas incorporadas, sin embargo, su elevado costo limita bastante su accesibilidad y son inadecuados para la implementación en tiempo real.
Arduino Uno y Raspberry Pi fueron los microprocesadores(MCU) más utilizados como puertas de enlace para sus monitoreos.
26 estudios prefieren almacenar sus datos de IAQ en servidores de la nube debido a su fácil accesos a las actualizaciones desde cualquier lugar y momento, convirtiéndola así en la fuente de almacenamiento de datos con mayor comodidad y uso.
Los métodos de consulta de datos preferidos son mediante app móviles y páginas webs.
Las fuentes de energía preferidas para ejecutar monitoreos de IAQ fueron las fuentes de alimentación, seguido del uso de baterías externas. Las células solares también fueron utilizadas como fuentes de energía para monitoreos de IAQ, mas solo se implementaron en dos estudios.

**Referencia: https://www.mdpi.com/1660-4601/17/14/4942**

### Artículo 2. Continuous monitoring of indoor environmental quality using an Arduino-based data acquisition system
Describe el desarrollo de un sistema de monitoreo de calidad del aire que es a la vez asequible y portátil, basado en la plataforma Arduino. Este sistema utiliza un sensor fotoacústico para medir las concentraciones de PM2.5 y PM10 en el aire. Tiene una batería recargable y una unidad de almacenamiento,es un dispositivo autónomo que puede ser llevado a cualquier lugar. El sistema fue probado en un laboratorio y se ha demostrado que es capaz de medir las concentraciones de PM2.5 y PM10 con una precisión del 95%. Tiene un bajo costo, por lo tanto es accesible para muchos usuarios, es una herramienta prometedora para el monitoreo de calidad del aire en interiores.

<p align="center"><strong>Figura 2:</strong></p>
<p align="center">
  
</p>

**Referencia: https://www.sciencedirect.com/science/article/abs/pii/S2352710218301025**

### Artículo 3. A systematic review and meta-analysis of field studies of portable air cleaners: Performance, user behavior, and by-product emissions
El artículo aborda la eficacia de los purificadores de aire portátiles (PAC) en la reducción de la contaminación del aire en espacios interiores. Estos dispositivos emplean diversos métodos, como filtros u otras tecnologías, para eliminar contaminantes como partículas finas, gases y elementos biológicos del aire.

Se llevaron a cabo estudios en varias partes del mundo, con un enfoque particular en América del Norte, Asia y Europa. Los resultados de esta revisión indican que los PAC pueden ser eficaces para disminuir la contaminación del aire en entornos cerrados. Sin embargo, la eficiencia varía dependiendo del tipo de contaminante, la tecnología de limpieza utilizada y el comportamiento del usuario.

Se observa que los PAC son más efectivos para reducir las partículas finas en comparación con los contaminantes gaseosos o biológicos. Entre las tecnologías de limpieza más eficaces para las partículas finas se encuentran los filtros HEPA y los filtros de carbón activado. Poseen el potencial de mejorar la calidad del aire en ambientes interiores. No obstante, se destaca la necesidad de realizar más investigaciones para comprender a fondo su eficacia y seguridad.

<p align="center"><strong>Figura 3:</strong></p>
<p align="center">
  
</p>

<p align="center"><strong>Figura 4:</strong></p>
<p align="center">
  
</p>

**Referencia: https://www.sciencedirect.com/science/article/abs/pii/S0048969723074156**

### Articulo 4. Long-term exposure to PM and all-cause and cause-specific mortality: A systematic review and meta-analysis(Exposición a largo plazo a PM y mortalidad por todas las causas y por causas específicas: una revisión sistemática y un metanálisis)

En base a la revisión sistemática, se evidencia que las partículas PM2.5 representan un riesgo significativo para la salud, con asociaciones claras a mayor mortalidad por diversas causas, incluyendo enfermedades cardiovasculares, respiratorias y cáncer de pulmón. Los riesgos relativos combinados revelan un aumento de 1,08 en la mortalidad por causas naturales por cada incremento de 10 µg/m3 de PM2.5, y 1,04 por cada 10 µg/m3 de PM10.

A pesar de un aumento sustancial en la base de evidencia, la escasez de estudios en países de ingresos bajos y medianos destaca la necesidad de más investigación. Las asociaciones persistentes con PM2.5, incluso por debajo de los niveles actuales de exposición recomendados por la OMS, subrayan la importancia crítica de abordar la contaminación del aire para salvaguardar la salud pública.
<p align="center"><strong>Figura 5:</strong></p>
<p align="center">
  
</p>

**Referencia: https://pubmed.ncbi.nlm.nih.gov/32703584/**

## CONTEXTO COMERCIAL 💻
### **Dispositivos en el mercado o equipos:**
#### Producto #1:
### <p align="center">Medidor de CO2 PCE-AQD 50-ICA</p>
**Finalidad:** Mide temperatura, humedad, presión atmosférica, CO2
<p align="center"><strong>Figura 6:</strong></p>
<p align="center">
  
</p>

**Descripción:** El medidor de CO2 integra diferentes sensores. Entre ellos está un sensor que mide el dióxido de carbono hasta 40 000 ppm, un sensor de temperatura para un rango entre 0 y +50 ºC, un sensor que mide la humedad del aire entre 0 y 100 % H.r. Gracias a los diferentes sensores que integra el medidor de CO2 puede usarlo en múltiples aplicaciones. Puede visualizar los valores en la pantalla digital del medidor de CO2. Además, incluye una valoración Bien / Regular / Mal de la concentración de CO2 del aire. La pantalla digital de bajo consumo permite aumentar la autonomía del acumulador del medidor de CO2.

**Enlace:** [Aqui](https://www.pce-instruments.com/peru/instrumento-medida/medidor/medidor-de-co2-pce-instruments-medidor-de-co2-pce-aqd-50-ica-incl.-certificado-calibraci%C3%B3n-det_6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)  
#### Producto #2:
### <p align="center">Medidor portátil de CO₂ GM70</p>
**Finalidad:** Amplio rango de medición y muestreo fácil
<p align="center"><strong>Figura 7:</strong></p>
<p align="center">
  
</p>

**Descripción:**  Es un medidor fácil de usar para mediciones de puntos exigentes en laboratorios, invernaderos, granjas de hongos, y para garantizar niveles de CO2 seguros durante procesos de embotellamiento de refrescos. A su vez, se puede usar el medidor en aplicaciones HVAC e industriales, y como herramienta para revisar instrumentos de CO2 fijos.

**Enlace:** [Aqui](https://www.vaisala.com/es/products/instruments-sensors-and-other-measurement-devices/instruments-industrial-measurements/gm70)  
#### Producto #3:
### <p align="center">Sensor detector de monóxido de carbono GK</p>
**Finalidad:** Electroquímico que mide el monóxido de carbono.
<p align="center"><strong>Figura 8:</strong></p>
<p align="center">
  
</p>

**Descripción:** El detector doméstico de monóxido de carbono (CO) es un detector de excelentes prestaciones y reducido tamaño, dada su construcción con materiales de gran resistencia brinda excelentes características de desempeño para la detección doméstica de monóxido de carbono. Cuando la lectura indicada por el sensor se encuentre en el umbral de alarma, el detector de gas ubicado en la parte frontal del instrumento, genera destellos para que puedan ser advertidos desde por el usuario y en la parte frontal del equipo se activará en el momento en el que la concentración de monóxido alcance o supere las 100 PPM. 

**Enlace:** [Aqui](https://www.valiometro.pe/sensor-detector-de-monoxido-de-carbono-gk) 

#### Producto #4:
### <p align="center">Medidor de partículas PCE-AQD 20</p>
**Finalidad:** Medición de temperatura, humedad del aire, CO2, PM2,5 y presión atmosférica.
<p align="center"><strong>Figura 9:</strong></p>
<p align="center">
  
</p>

**Descripción:** El medidor de partículas es un instrumento de medición ideal para controlar la calidad del aire en puestos de trabajo. El medidor de partículas es ideal para protocolar de forma continua la temperatura y humedad del aire, el CO2, las partículas PM 2,5 y la presión atmosférica. Todos estos parámetros sirven al encargado de salud y seguridad para conocer la calidad del aire. Los valores medidos con el medidor de partículas se guardan en una tarjeta de memoria SD. El formato del fichero es xls lo que le permite leer los valores directamente con el programa Excel sin la necesidad de pasar a través de un software. Los valores se visualizan en la gran pantalla retroiluminada.

**Enlace:** [Aqui](https://www.pce-instruments.com/peru/instrumento-medida/medidor/medidor-de-particulas-pce-instruments-medidor-de-part%C3%ADculas-pce-aqd-20-det_5909905.htm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)

### **Patentes:** 
#### Patente #1:
### <p align="center">_Dispositivo de aspiración y purificación de humos con función de recuperación de calor residua_</p>
**Fecha de publicación:** 2022-06-21

**Número de publicaciones:** CN216790309U

**Inventores:** TANG JIE; NI DAMANDO; LIU ZONGLING

<p align="center"><strong>Figura 10:</strong></p>
<p align="center">
  
</p>

**Descripción:** El dispositivo es un sistema de aspiración y purificación de humos para cocinas, con recuperación de calor residual. Con una carcasa en forma de L y mecanismo de intercambio de calor, recicla el calor del humo durante la purificación. La estructura incluye placas, tira guía, y un mecanismo de intercambio con aletas y tubos de absorción. Este diseño garantiza eficiencia al aprovechar el calor residual durante la aspiración y purificación de humos de cocina.(Tang J., 2022)

**Referencia:** TANG, J.; DAMING, N.; ZONGLING, L.(2022)Smoke suction and purification device with waste heat recovery function for kitchen. CN216790309U. Recuperado de https://worldwide.espacenet.com/patent/search/family/082010151/publication/CN216790309U?q=pn%3DCN216790309U

#### Patente #2:
### <p align="center">_Sistema de precipitación electrostática para captura de materia partícula en equipos de conbustión domésticos_</p>
**Fecha de publicación:** 2020-01-02

**Número de publicaciones:** WO2020000115A1

**Inventores:** SOTO ESPINACE, Ricardo; BURBOA VILLARROEL, Eduardo; SOTO VERA, Esteban

<p align="center"><strong>Figura 11:</strong></p>
<p align="center">
  
</p>

**Descripción:** La invención es un sistema de precipitación electrostática para capturar material particulado en equipos de combustión como estufas y calderas de biomasa. Incluye un tubo metálico, una caja de componentes eléctricos, una puerta con sensores de apertura y cierre, un electrodo removible y un conjunto eléctrico externo. La característica distintiva es la seguridad con sensores que apagan la fuente de alto voltaje al abrir la puerta, evitando descargas eléctricas. La amplitud de voltaje necesario para reducir el material particulado varía de 17kV a 38kV, con un valor máximo operativo de aproximadamente 28kV.(Soto E., 2020)

**Referencia:** SOTO ESPINACE, R.; BURBOA VILLARROEL, E.; SOTO VERA, E.(2020)ELECTROSTATIC PRECIPITATION SYSTEM FOR CAPTURING PARTICULATE MATTER IN HOME COMBUSTION EQUIPMENT. WO2020000115A1. Recuperado de https://worldwide.espacenet.com/patent/search/family/065529042/publication/WO2020000115A1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

#### Patente #3:
### <p align="center">_Dispositivo de humo y circuito de detección de humo_</p>
**Fecha de publicación:** 2021-06-01

**Número de publicaciones:** US11024141B2

**Inventor:** Eric V.Gonzales

<p align="center"><strong>Figura 12:</strong></p>
<p align="center">
  
</p>

**Descripción:** Un procedimiento para supervisar una ubicación llevado a cabo por uno o más procesadores incluye la recepción de señales provenientes de un sensor de humo. Posteriormente, se identifican una o más características distintivas a partir de las señales recibidas. Luego, se establece una ventana de tiempo basándose en al menos una de las características identificadas. Se caracterizan uno o más tipos de incendio dentro de la ventana de tiempo determinada utilizando las características identificadas. Además, se determinan de manera dinámica uno o más niveles de alarma según la caracterización de los tipos de fuego. Se evalúa al menos una característica dentro de la ventana de tiempo utilizando los niveles de alarma establecidos y, si se detecta una condición de alarma, se emite una señal de alarma.(Gonzales, 2021)

**Referencia:** Gonzales, E.(2021)  Smoke device and smoke detection circuit. US11024141B2. Recuperado de https://patentimages.storage.googleapis.com/c1/45/a8/021df7692b10cf/US11024141.pdf
### Patente #4:
### <p align="center">_Ventilador de escape de humo electrónico de protección del medio ambiente y aparato de absorción de electrones de humo_</p>
**Fecha de publicación:** 2008-11-12

**Número de publicaciones:** CN100431711C

**Inventores:** TAO XIANFANG

<p align="center"><strong>Figura 13:</strong></p>
<p align="center">
  
</p>

**Descripción:** La tecnología absorbe el polvo utilizando electricidad estática para ionizar y cargar las partículas de humo, luego utiliza un fuerte campo eléctrico para desviar y absorber las partículas de humo cargadas para generar iones de oxígeno negativos,que contribuyen a refrescar y esterilizar el aire.
Utiliza un fuerte campo eléctrico generado por un alto voltaje para ionizar las partículas de humo o la mezcla en el humo para cargarlo, y luego usa la misma electricidad para repelerse entre sí. El principio de atracción mutua, reciclarlo. Una vez recuperados los vapores de aceite, el gas descargado por la campana extractora electrónica respetuosa con el medio ambiente apenas contiene vapores de aceite u otras impurezas, y todo es aire puro, lo que equivale a filtrar el aire contaminado. (XIANFANG. ,2008)

**Referencia:** XIANFANG, T. (2008) Environmental protection electronic smoke exhaust ventilator and smoke electron absorption apparatus. CN100431711C. Recuperado de https://worldwide.espacenet.com/patent/search?q=pn%3DCN100431711C

## REQUERIMIENTOS 


funciFun

## Bibliografía
Chen, J., & Hoek, G. (2020). Long-term exposure to PM and all-cause and cause-specific mortality: A systematic review and meta-analysis. Environment international. Recuperado de https://doi.org/10.1016/j.envint.2020.105974

Ebrahimifakhar, A., Poursadegh, M., Hu, Y., Yuill, D. P., & Luo, Y. (2024). A systematic review and meta-analysis of field studies of portable air cleaners: Performance, user behavior, and by-product emissions. Science of The Total Environment. Recuperado de https://doi.org/10.1016/j.scitotenv.2023.168786

Gonzales, E. (2021). Smoke device and smoke detection circuit. US11024141B2. Recuperado de https://patentimages.storage.googleapis.com/c1/45/a8/021df7692b10cf/US11024141.pdf

Karami, M., McMorrow, G. V., & Wang, L. (2018). Continuous monitoring of indoor environmental quality using an Arduino-based data acquisition system. Journal of Building Engineering. Recuperado de https://doi.org/10.1016/j.jobe.2018.05.014

Li, C., Zhang, K., Dai, Z., Ma, Z., & Liu, X. (2020). Investigation of the Impact of Land-Use Distribution on PM2.5 in Weifang: Seasonal Variations. International Journal of Environmental Research and Public Health. Recuperado de https://doi.org/10.3390/ijerph17145135

SOTO ESPINACE, R.; BURBOA VILLARROEL, E.; SOTO VERA, E. (2020). Electrostatic precipitation system for capturing particulate matter in home combustion equipment. WO2020000115A1. Recuperado de https://worldwide.espacenet.com/patent/search/family/065529042/publication/WO2020000115A1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

TANG, J.; DAMING, N.; ZONGLING, L. (2022). Smoke suction and purification device with waste heat recovery function for kitchen. CN216790309U. Recuperado de https://worldwide.espacenet.com/patent/search/family/082010151/publication/CN216790309U?q=pn%3DCN216790309U

XIANFANG, T. (2008). Environmental protection electronic smoke exhaust ventilator and smoke electron absorption apparatus. CN100431711C. Recuperado de https://worldwide.espacenet.com/patent/search?q=pn%3DCN100431711C

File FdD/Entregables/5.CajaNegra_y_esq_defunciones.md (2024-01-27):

# Metodologia de Diseño
## “Caja Negra” y Esquema de Funciones

### Índice
* [Caja_Negra](#Caja_Negra)
   * [Descripción](#Entradas_y_salidas)
* [Esquema_de_Funciones](#Esquema_de_Funciones)
   * [Descripción](#Descripción)
## Caja Negra
cajaNegra

## Entradas y Salidas
### Entradas

* Fuente de Alimentación: Utilizaremos una fuente de energia renovable para el funcionamiento del dispositivo.
* Componentes gaseosos (C.G): Al dispositivo ingresarán compuestos gaseosos(co, co2, material partículado2.5) para su futura medición.

### Salidas
* Información: Los sensores enviarán la medición de los C.GyS a una base de datos en tiempo real.
* Alarma sonora/visula: Cuando la medición de C.GyS sobrepasen el límite máximo establecido, el dispositivo emitirá un sonido específico de termino medio(80db-100db). 

## Esquema de Funciones
esquema

## Descripción de funciones

descripcion

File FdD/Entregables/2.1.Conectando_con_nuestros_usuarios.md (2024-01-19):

# Conexión con nuestros usuarios
Descripción de los diagramas que nos explica más la situación y problemática que nos hizo elegir esta causa. 

### Indice:
* [Diagrama de empatía](#diagrama-de-empatía)
  * [Referencias](#referencias)
* [Journey Map/ Mapa de viaje](#mapa-de-viaje)
  * [Referencias](#referencias-1)
* [Diagrama de Ishikawa](#diagrama-de-ishikawa)
  * [Referencias](#referencias-2)

## Diagrama de empatía
#### **Usuario: Hospital Departamental de Huancavelica "Zacarías Correa Valdivia"**
Imagen
#### **Usuario: MINAM**
Imagen
### Referencias:
Ramos, I. (2019, 31 de agosto). "Somo pobres": Así es tener que cocinar con leña por obligación. https://www.radiofeyalegrianoticias.com/asi-es-tener-que-cocinar-con-lena-por-obligacion/

Ayala, E. (2022, 12 de septiembre). Cocinar con leña: una práctica que nos daña tanto como el humo de los autos. https://saludconlupa.com/climatopedia/cocinar-con-lena-una-practica-que-nos-dana-tanto-como-el-humo-de-los-autos/

Novogas. (2023, 3 de julio). Más de un millón de hogares cocinan con leña en el Perú. https://www.linkedin.com/pulse/m%C3%A1s-de-un-mill%C3%B3n-hogares-cocinan-con-le%C3%B1a-en-el-per%C3%BA-novogaslatam/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

## Mapa de viaje 
Imagen

### Referencias:
Organización Mundial de la Salud (OMS). (15 de diciembre de 2023). Household air pollution and health. https://www.who.int/es/news-room/fact-sheets/detail/household-air-pollution-and-health

Net Noticias. (27 de julio de 2023). Cocinas sucias; un tercio de la población aún usa leña o carbón para cocinar. https://netnoticias.mx/de-interes/cocinas-sucias-un-tercio-de-la-poblacion-aun-usa-lena-o-carbon-para-cocinar

Wong, E. (2022). Implementación de cocinas mejoradas a leña y disminución de GEI. Ingeniería Investiga, 4, e712. https://doi.org/10.47796/ing.v4i0.712

El Comercio. (8 de septiembre de 2021). La cocina sostenible: el impacto de cocinar con menos leña. https://especial.elcomercio.pe/perusostenible/la-cocina-sostenible-el-impacto-de-cocinar-con-menos-lena/

## Diagrama de Ishikawa
Imagen
### Referencias:
Wong, E. (2022). Implementación de cocinas mejoradas a leña y disminución de GEI. Ingeniería Investiga, 4, e712. https://doi.org/10.47796/ing.v4i0.712
Ramos, I. (2019, 31 de agosto). "Somos pobres": Así es tener que cocinar con leña por obligación. https://www.radiofeyalegrianoticias.com/asi-es-tener-que-cocinar-con-lena-por-obligacion/

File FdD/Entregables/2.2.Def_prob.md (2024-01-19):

# Problemática
Huancavelica es una de las regiones con una alta tasa de uso de combustibles fósiles para cocinar, debido a la escases de recursos financieros por parte de sus habitantes; según el INEI el 23,1% de la población general de huancavelica usa combustibles limpios(INEI,2022), esto quiere decir que el otro 76,9% usan combustibles no limpios, esto genera consecuencias directas tanto en la salud de la población de huancavelica como en el medio ambiente. Dos de todos los contaminantes principales son el dioxido de carbono(CO2) y las partículas de material particulado(PM2.5). Ambos son tóxicos tanto como para los humanos y para el medio ambiente. Por el lado del impacto en la salud el exponerse al humo generado por el dióxido de carbono puede causar dolor de cabeza, dificultad para respirar; pero una exposición mas alta podría llegar  causar convulsiones, coma y hasta la muerte(NJHEALTH,2016), asimismo la exposcición a las partículas de material particulado(PM2.5) puede afectar tanto a los pulmones como al corazón(EPA,2023). Por el lado del impacto ambiental el CO2 producido contribuye al sobrecalentamiento global y cambio climático, asimismo es uno de los gases responsables de producir el efecto invernadero(ecología verde,2019). Esto es un problema para las personas que se exponen a este gas tóxico y también para el personal y sistema de salud en Huancavelica, debido a la escasa información precisa y actualizada sobre las emisiones de CO2 en las viviendas y comunidades.

### Figura 1
Perú: Proporción de la población cuya fuente primaria de energía para cocinar los alimentos son los combustibles y
tecnologías limpios, según departamento
(Porcentaje)
Imagen
Nota: Gráfico en porcentajes. Tomada de (INEI,2021)

### Referencias:

Instituto Nacional de Estadística e Informática (INEI). (diciembre de 2022). Libro estadístico. https://www.inei.gob.pe/media/MenuRecursivo/publicaciones_digitales/Est/Lib1881/libro.pdf

New Jersey Department of Health. (julio de 2016). Lead in Water: Reducing Lead Exposure - Spanish. https://www.nj.gov/health/eoh/rtkweb/documents/fs/0343sp.pdf

Ecología Verde. (3 de abril de 2019). El impacto medioambiental del dióxido de carbono. https://www.ecologiaverde.com/el-impacto-medioambiental-del-dioxido-de-carbono-1334.html

Agencia de Protección Ambiental de los Estados Unidos (EPA). (10 de mayo de 2023). Efectos del material particulado (PM) sobre la salud y el medioambiente. https://espanol.epa.gov/espanol/efectos-del-material-particulado-pm-sobre-la-salud-y-el-medioambiente

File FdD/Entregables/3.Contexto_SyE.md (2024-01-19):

# Contexto Social y Económico 

###  *Indice:*
* [Contexto Social](#contexto-social)
  * [Contexto social mundial](#contexto-económico-mundial)
  * [Contexto social nacional](#contexto-social-nacional)
* [Contexto Económico](#contexto-económico)
    * [Contexto económico mundial](#contexto-económico-mundial)
    * [Contexto económico latioamérica/Caribe](#contexto-económico-latinoaméricacaribe)
    * [Contexto económico nacional](#contexto-económico-nacional)
* [Referencias](#referencias)

## Contexto Social

### Contexto Social Mundial: 

El acceso a servicios energéticos no contaminantes tienen un gran impacto en el desarrollo sostenible. La energía no contaminante es una fuente de energía sostenible que ayuda a no depender de los combustibles fósiles, ya que estos tienen un efecto negativo en la salud del ser humano y del medio ambiente. Sin embargo, no es accesible en muchos lugares ya sea por la falta de economía o por el difícil acceso. 

Según la Organización de las Naciones Unidas (ONU,2023), en el 2021, el 29% de la población en el mundo (2.300 millones) siguen dependiendo de las combustibles fósiles para preparar sus alimentos, dando como resultado negativo la contaminación ambiental y limita sus oportunidades de vida, dado que pone en peligro su salud. Asia sudoriental tuvo un progreso positivo , logrando que las tres cuartas partes tengan acceso a la energía no contaminante. Por otro lado, África subsahariana tuvo resultados negativos. Si la situación continúa en el mismo ritmo, para el 2030 solo el 70% de la población tendrá acceso a combustibles no contaminantes.

##### Figura 1

Cifra absoluta de personas y proporción de la población mundial con acceso a
combustibles y tecnologías no contaminantes para cocinar, 2015-2021
(miles de millones y porcentaje)

Imagen

Nota. Proporción del 2015 al 2021. Tomado de (unstats,2023)

##### Figura 2

Población con acceso a sistemas para cocinar no contaminantes, 2020
(porcentaje)

Imagen

Nota. Gráfico geográfico con valores en porcentaje. Tomado de (unstats,2022)

Por otro lado , del año 2010 al 2020 aumentó la tasa de accesibilidad de un 81% a 91%. Las cifras se redujeron de 1,2 mil millones a 733 millones. Sin embargo, con la llegada del Covid-19 redujo el proceso , dando como resultado que sea más difícil alcanzar la accesibilidad energética.

##### Figura 3

Proporción de la población con acceso a energía eléctrica

Imagen

Nota. Proporción desde el 2010 hasta el 2020. Tomado de (unstats,2022)
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

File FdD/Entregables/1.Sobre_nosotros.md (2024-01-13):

# Grupo 11
#### Somos un equipo de estudiantes apasionados de Ingeniería Informática y Ambiental de la Universidad Peruano Cayetano Heredia, unidos por el propósito de fusionar la tecnología con la sostenibilidad. 
<h3 align="center">Grupo 👥 </h3>
<p align="center">
  
</p> 

## Integrantes:

* [Said Andre Quispe Diaz](#Said-Andre-Quispe-Diaz) 📰 _(Coordinadora de investigacion y experiencia de ususario)_

  * Correo electronico: 
    
* [Milagros Soledad Acevedo Valer ](#Milagros-Soledad-Acevedo-Valer) 💻 _(Coordinadora de diseño de software y soporte)_

  * Correo electronico: milagro.acevedo@upch.pe
* [Daniel Rodrigo Hermoza Quispe](#Daniel-Rodrigo-Hermoza-Quispe) 💡 _(Coordinador general y área electrónica)_

  * Correo electronico:
* [Jander Huamani Salazar](#Jander-Huamani-Salazar) 📊 _(Coordinador de diseño y manufactura)_

  * Correo electronico:
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

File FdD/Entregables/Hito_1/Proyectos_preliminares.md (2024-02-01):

<h1 align="center">🖊Proyectos preliminares🖌</h1>

### Lista de contenido:
* [Bocetos](#bocetosproyectos-preliminares)
  * [Proyecto preliminar 1](#proyecto-preliminar-1)
  * [Proyecto preliminar 2](#proyecto-preliminar-2)
  * [Proyecto preliminar 3](#proyecto-preliminar-3)
  * [Proyecto preliminar 4](#proyecto-preliminar-4)
* [Matriz de evaluación](#matriz-de-evaluación)
    * [Evaluación técnica](#matriz-de-evaluación-técnica)
    * [Evaluación económica](#matriz-de-evaluación-económica)
* [Proyecto óptimo](#proyecto-óptimo)
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

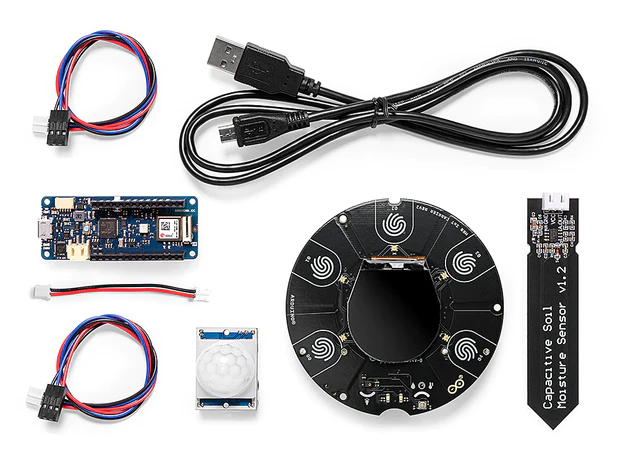
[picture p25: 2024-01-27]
Imagenes/lab2/image.png

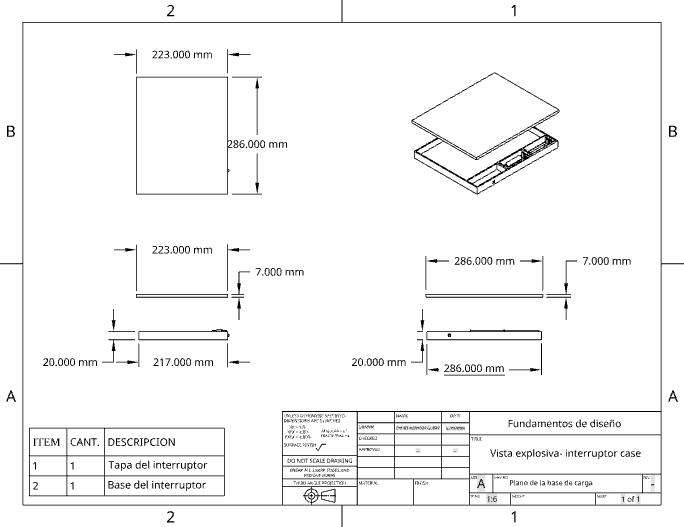
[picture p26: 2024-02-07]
Imagenes/img_entregable7/planointerru.png

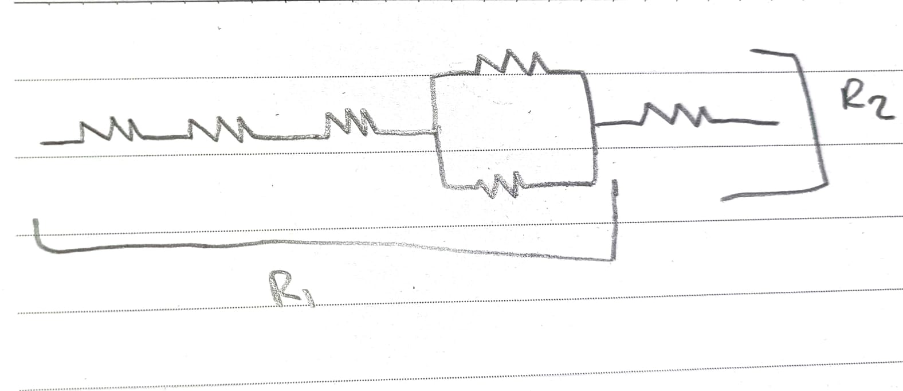
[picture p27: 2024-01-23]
Imagenes/lab2/Imagen de WhatsApp 2024-01-22 a las 22.01.40_8af0095c.jpg

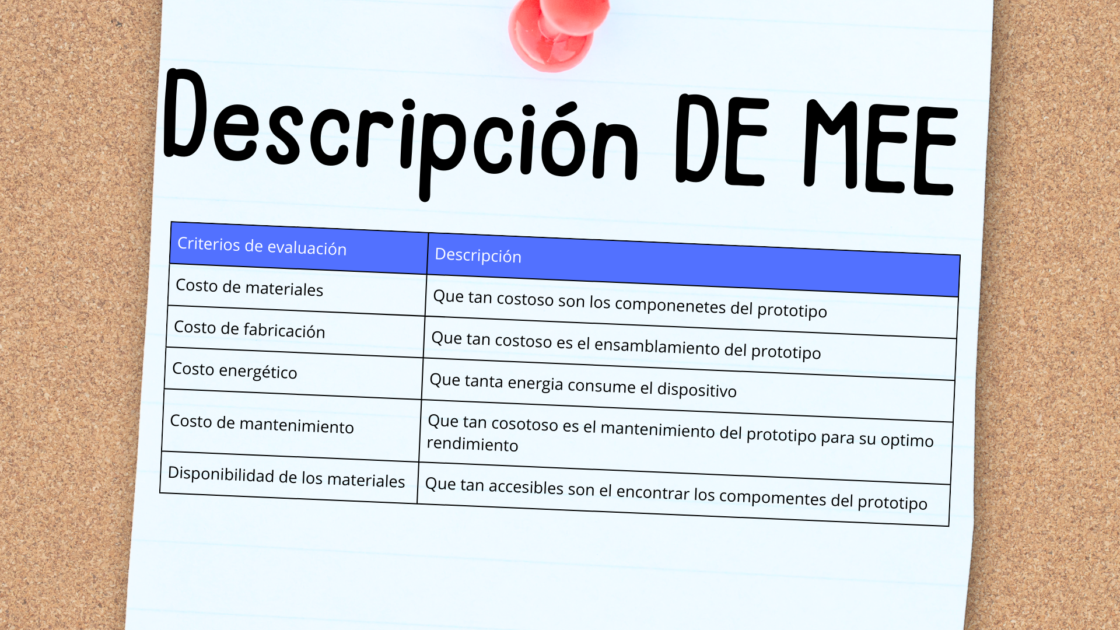
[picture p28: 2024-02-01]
Imagenes/img_hito1/dif_eco.png

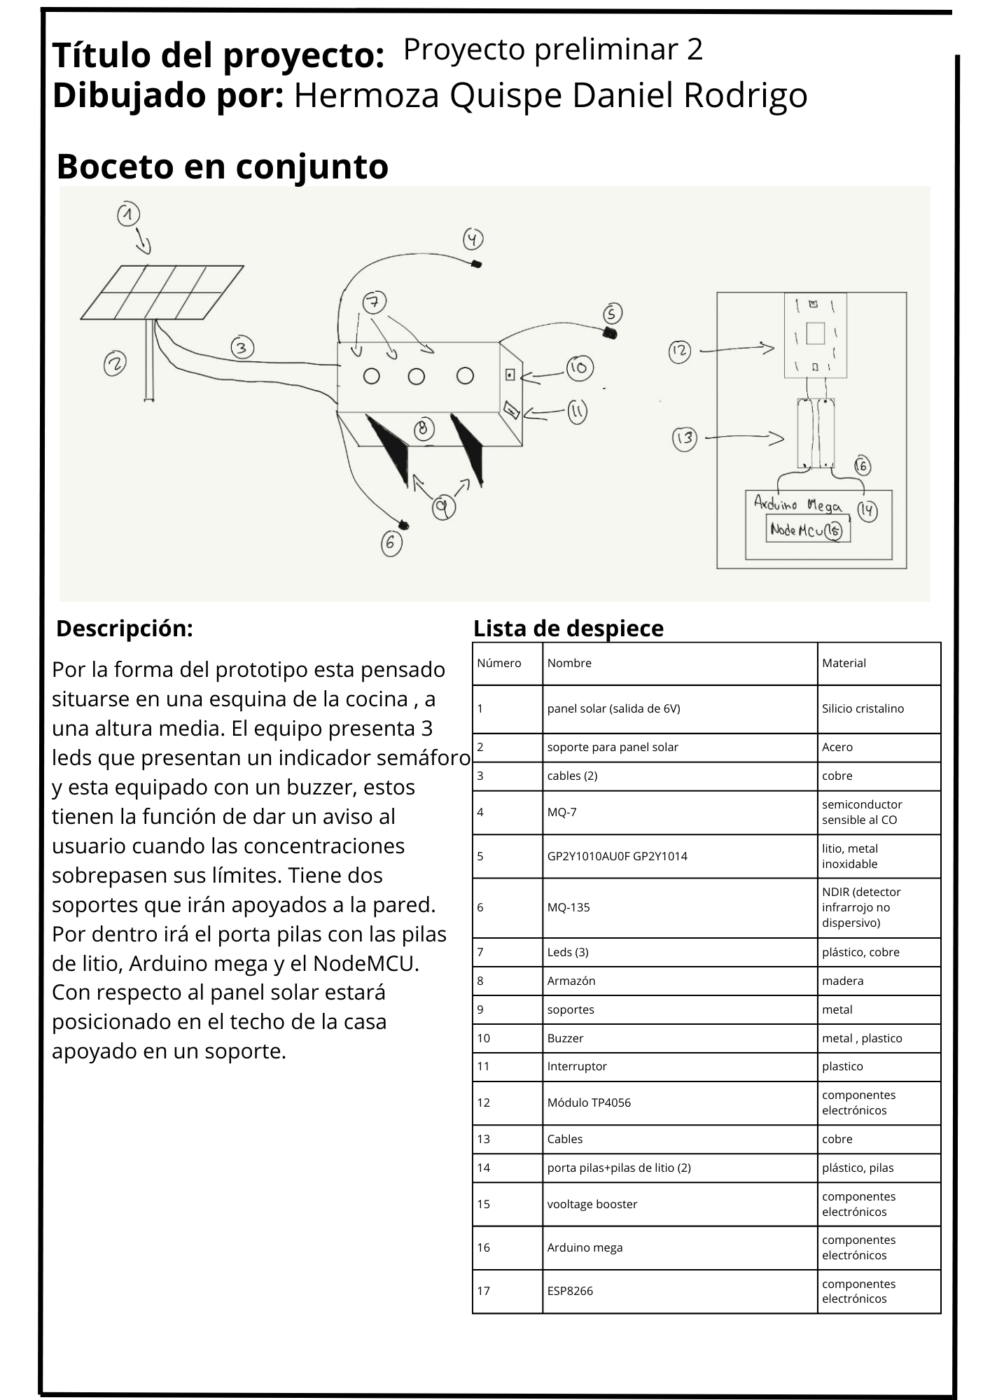
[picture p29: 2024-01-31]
Imagenes/img_hito1/boceto2.png

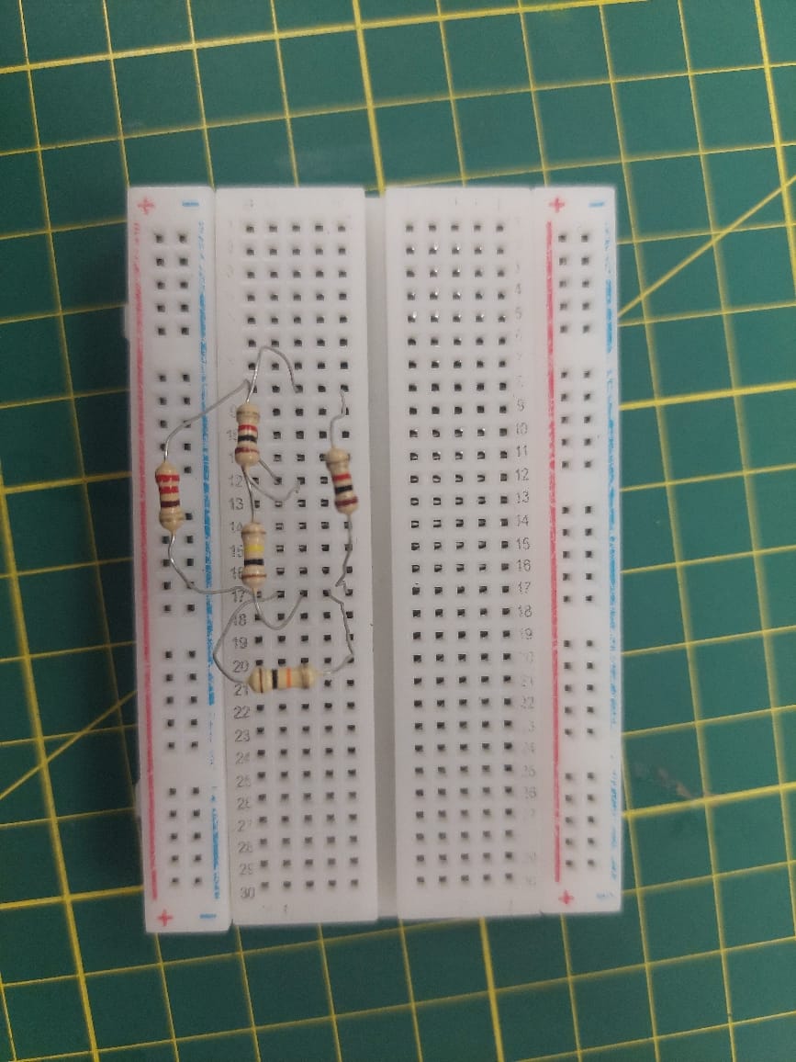
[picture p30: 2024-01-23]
Imagenes/lab2/Imagen de WhatsApp 2024-01-22 a las 15.26.20_7a8a405e.jpg

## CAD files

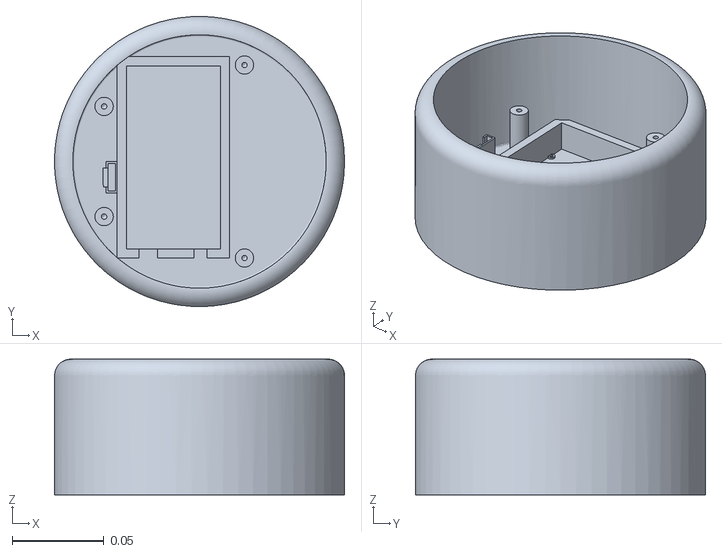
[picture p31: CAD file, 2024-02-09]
Hardware/Impresión/BASE.stl
0.158 x 0.158 x 0.074

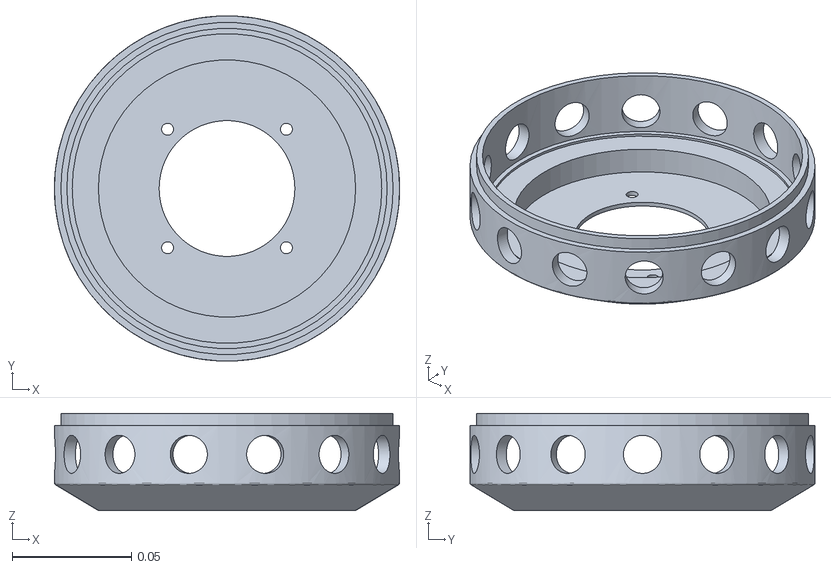
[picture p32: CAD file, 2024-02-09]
Hardware/Impresión/TAPA.stl
0.145 x 0.145 x 0.0408

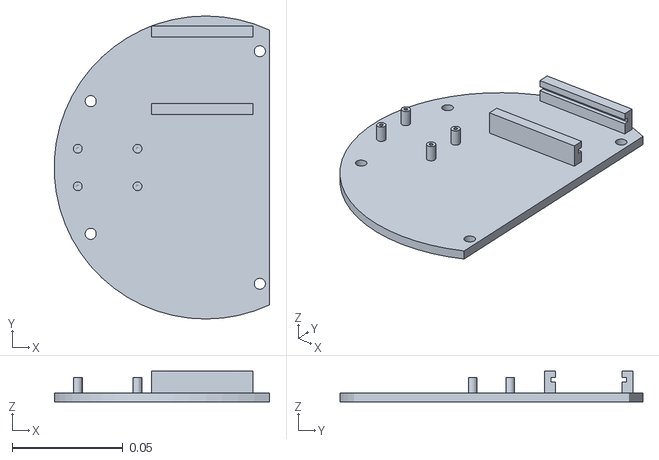
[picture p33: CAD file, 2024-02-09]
Hardware/Impresión/tapa_parala_base.stl
0.0973 x 0.137 x 0.014

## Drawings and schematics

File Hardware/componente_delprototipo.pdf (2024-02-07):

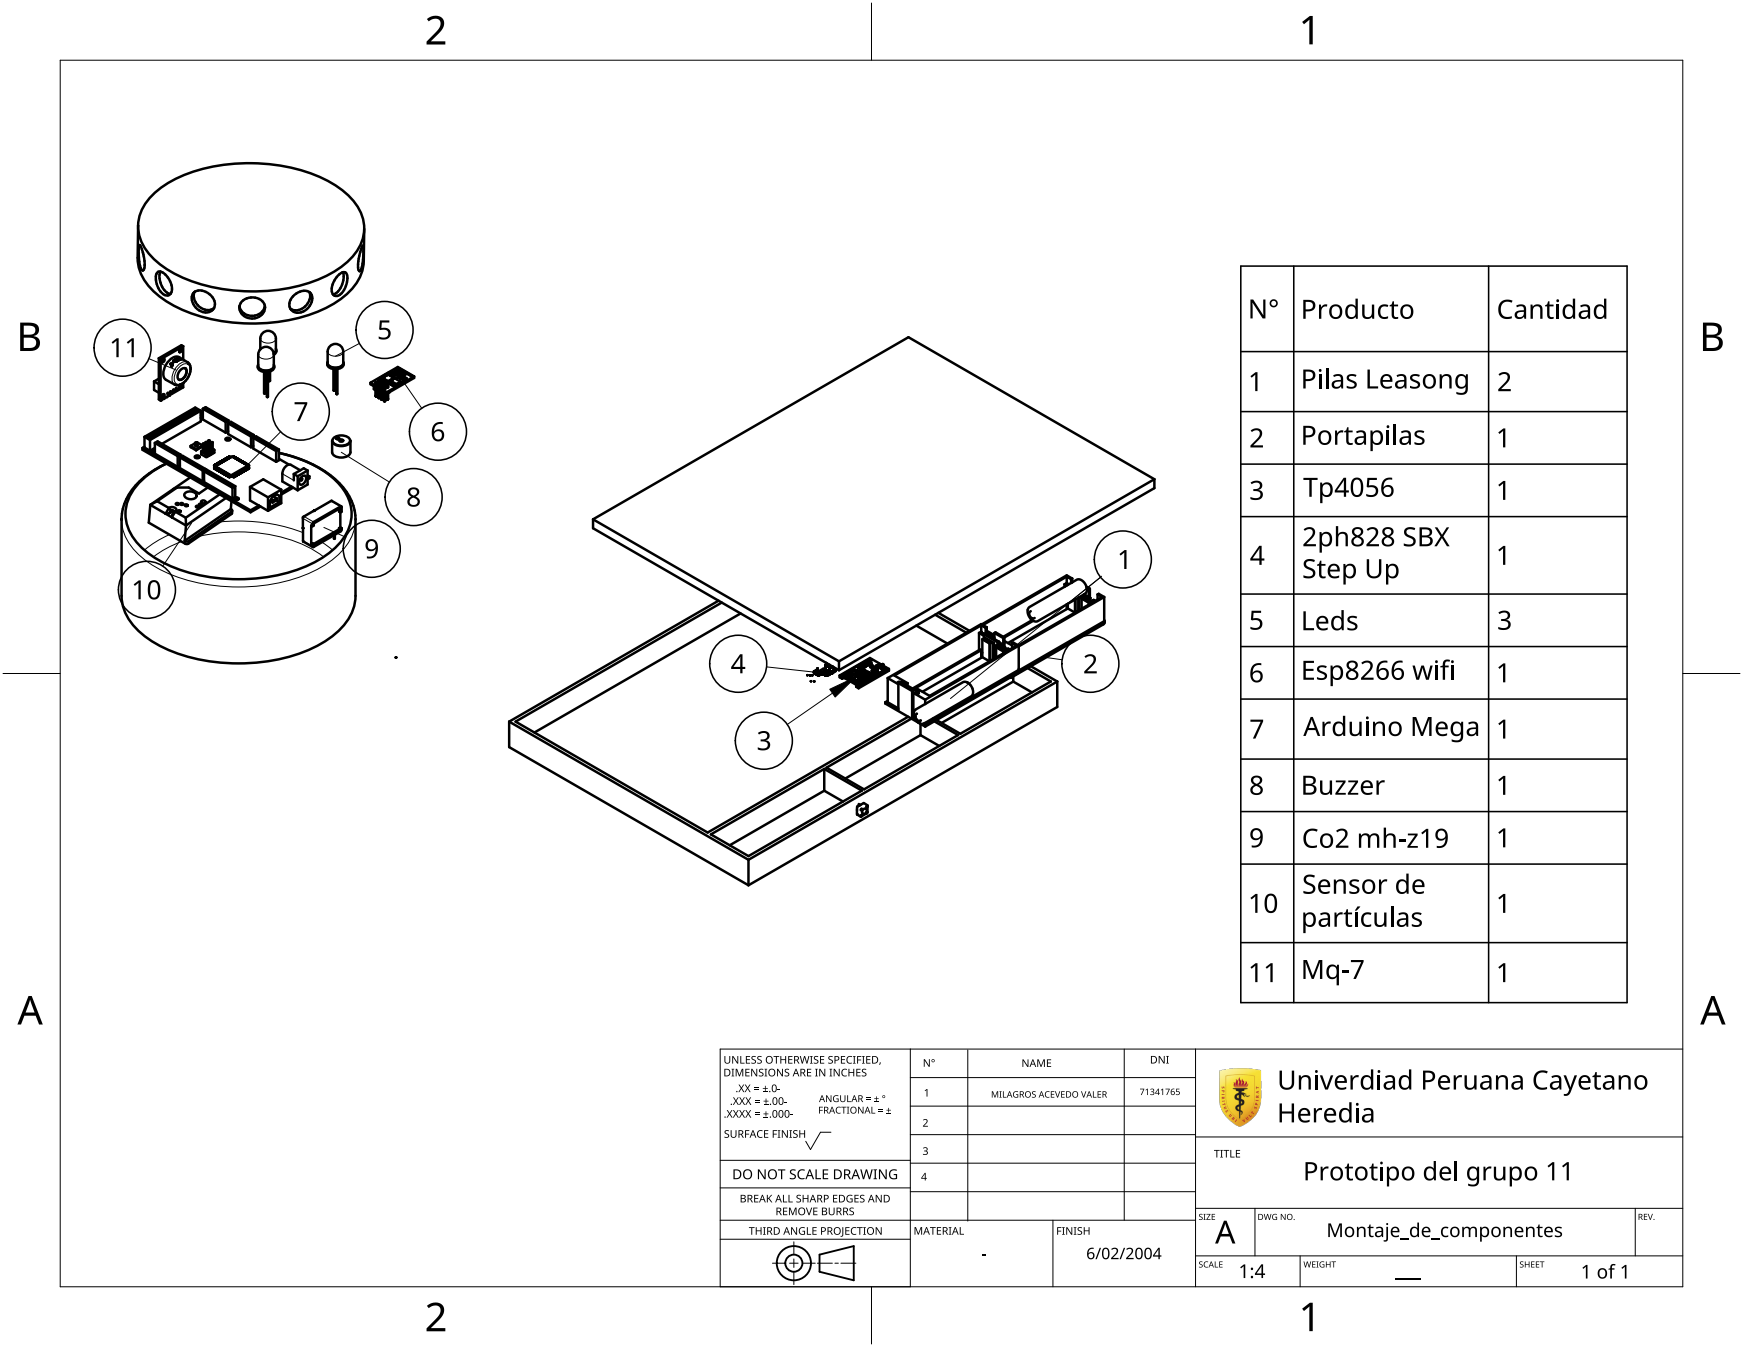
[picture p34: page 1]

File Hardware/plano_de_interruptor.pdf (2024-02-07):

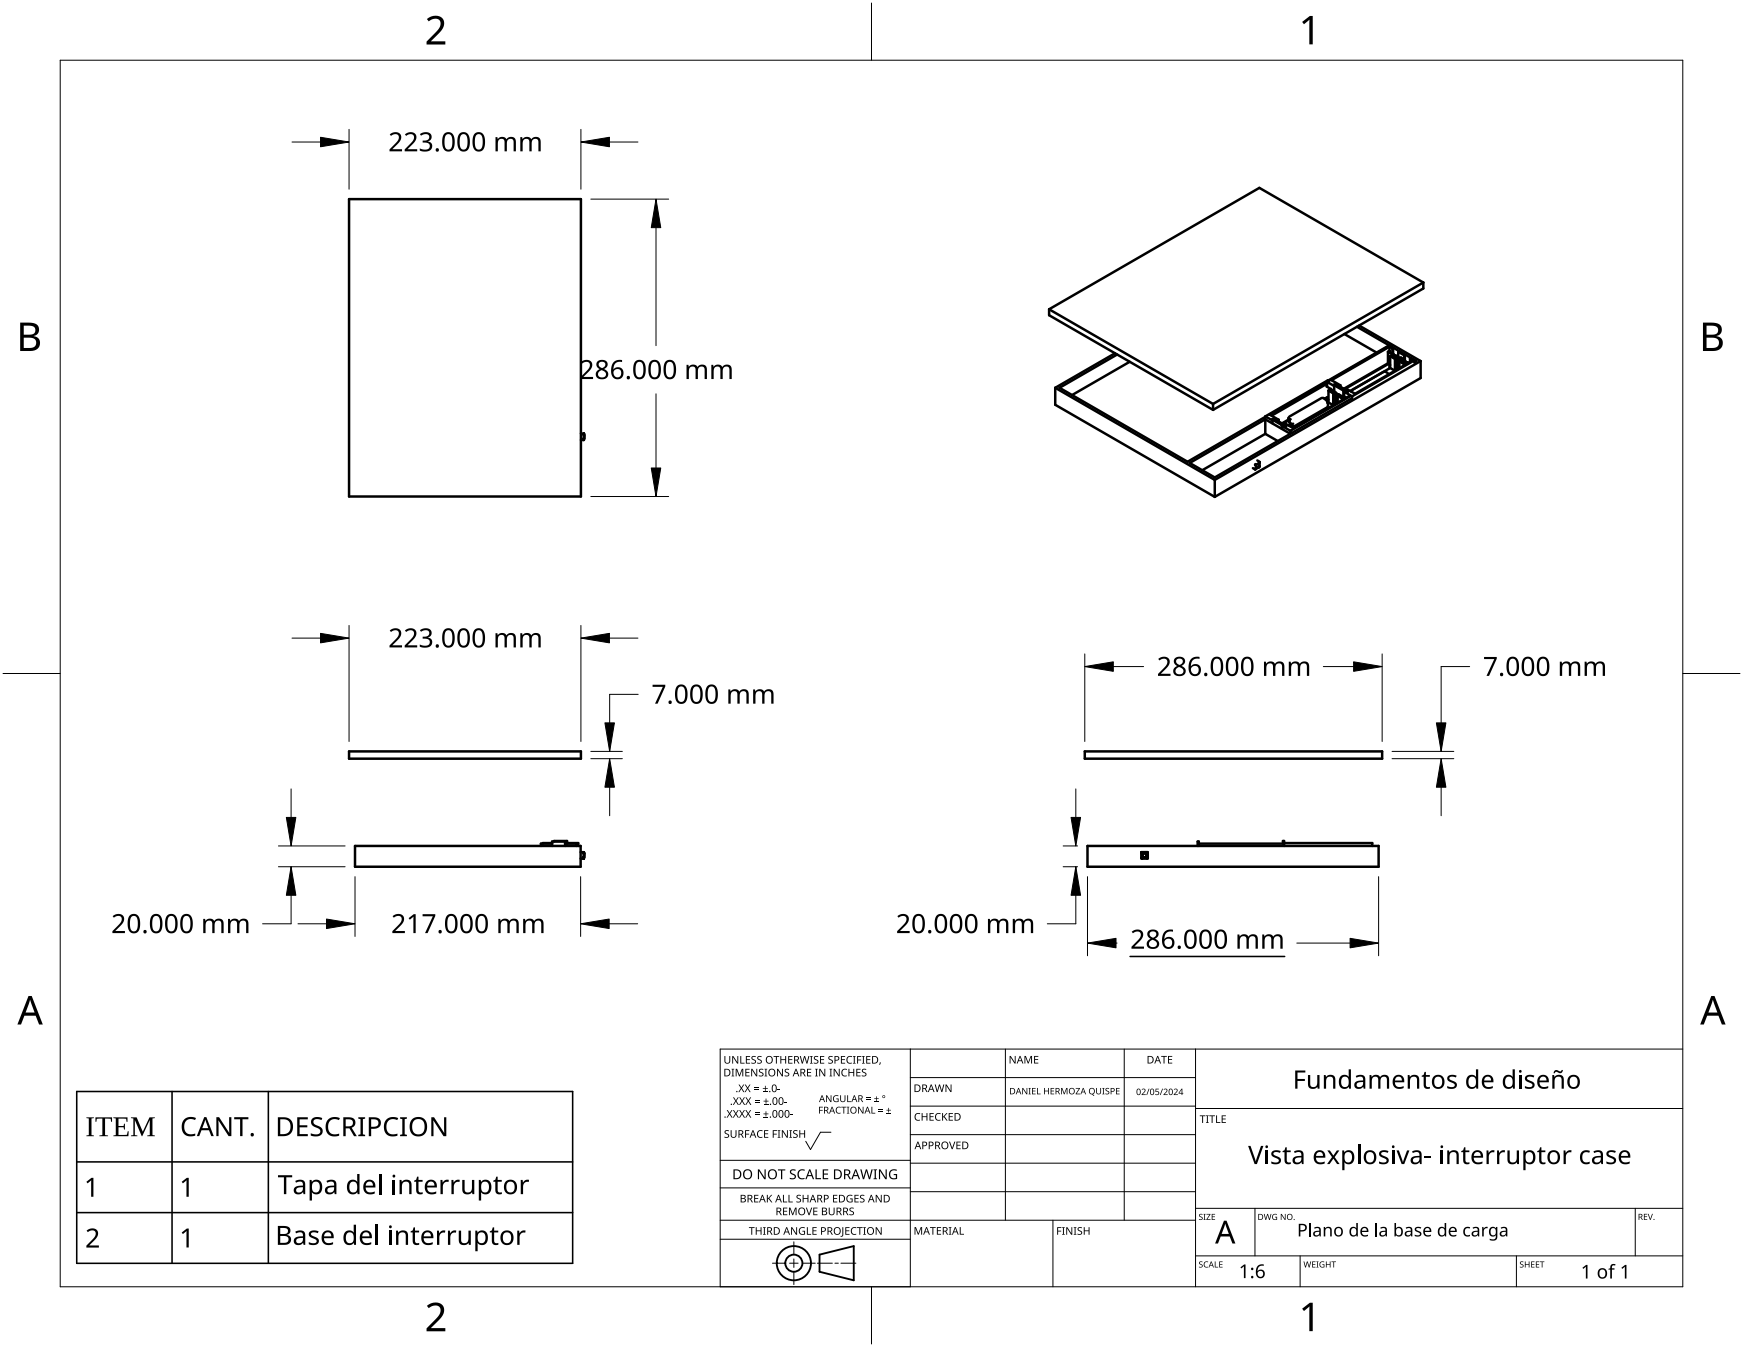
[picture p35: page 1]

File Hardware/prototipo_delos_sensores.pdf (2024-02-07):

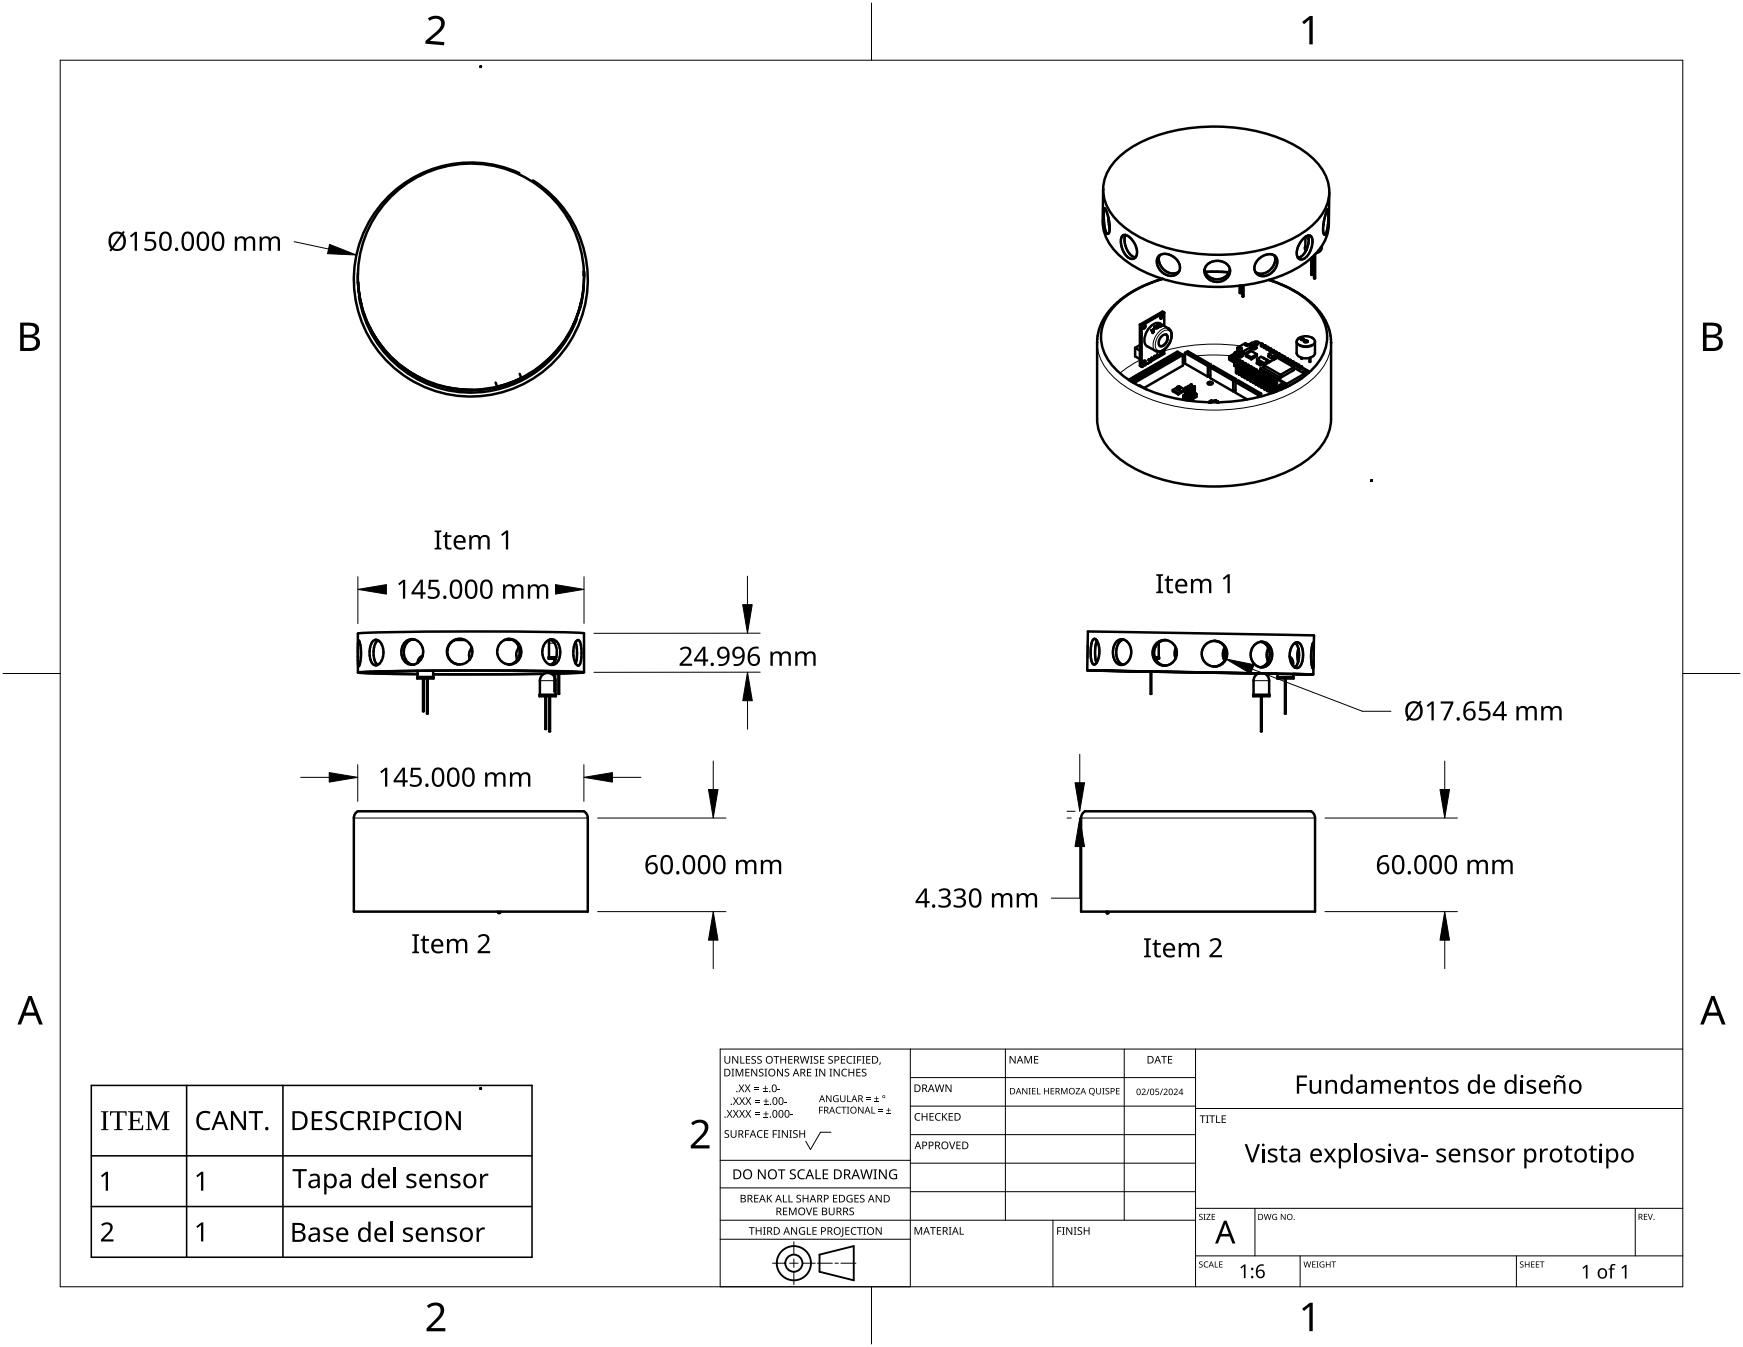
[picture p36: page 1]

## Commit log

2024-01-11 cambio de tabla
2024-01-11 cambios de readme de carpetas
2024-01-11 cambios de sobrenosostros
2024-01-12 cambio de nombre de carpeta y informacion añadida
2024-01-15 mapa de empatia
2024-01-15 añadido indice de contexto
2024-01-17 cambio de URL no funcional README.md
2024-01-18 error del nombre por que no se visualizaba
2024-01-19 Artículo de Sistemas de monitoreo
    Contexto científico
2024-01-19 imagen de Portada de artículo
2024-01-19 tabla de requerimientos funsionales
2024-01-25 main https://github.com/Dooncito/fundamentos-de-dise-o
2024-01-26 Captura de pantalla 2024-01-25 213411.png to Caja_Negra.png
2024-01-26 Rename Captura de pantalla 2024-01-25 214011.png to Esquema_de_Funciones.png
2024-01-31 Add files via upload
    Tuvimos problema con el tamaño principal de pdf siendo de 85mb, y el github solo acepta maximo 25mb. Nos demoramos en comprimirlo. Disculpe en eso .
2024-02-01 corrección de la presentación
